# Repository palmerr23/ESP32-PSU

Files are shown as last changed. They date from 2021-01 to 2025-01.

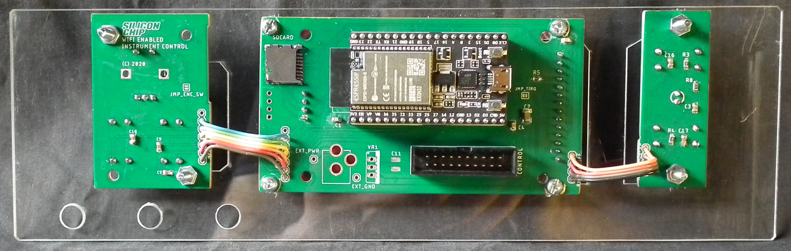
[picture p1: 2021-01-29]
Laser_templates/Control panel template 2.png

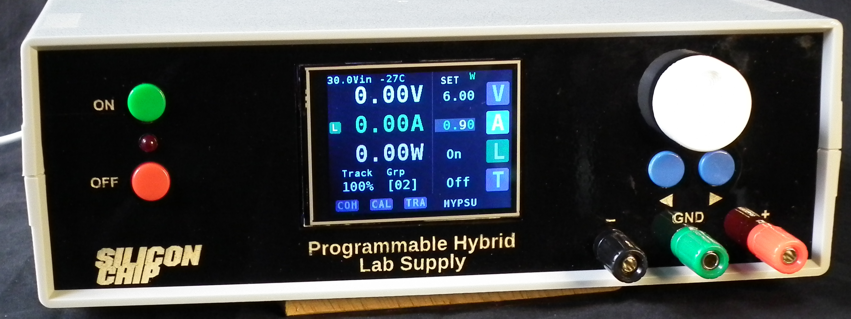
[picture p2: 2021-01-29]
Laser_templates/front panel.png

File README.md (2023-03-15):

# ESP32-PSU

These files relate to a project published in Silicon Chip magazine in May/June 2021. https://www.siliconchip.com.au/

A general purpose ESP32 breakout board, optimised for lab instrument control, and a single channel hybrid power supply module.

Two separate versions of the Open Weather code are provided for the 2.8" and 3.5" display options. They should be compiled and loaded using your own OWM token. https://openweathermap.org/appid

For the Hybrid Power Supply, only compiled code is provided for 2.8" and 3.5" versions (ILI9341 and ILI9488 LCD controllers) because the number of libraries and complexity of code would make it difficult for others to get a clean compile.   

The Laser_Templates folder has SVG files for the front and rear panels of the power supply. There are separate versions for the 2.8" and 3.5" display options. In each front panel file there are two templates: the front panel itself (with colour coded cut [outlines] and etch [labels] elements) and a second template for a panel to support the display and controller PCBs (avoiding front panel screws). A reinforcing plate for the binding posts is also included. It is fitted behnd the front panel.

The front and supporting panels were cut from 2mm acrylic and the back panel from the plastic insert provided with the case.

The laser templates are designed for a Pro'skit 203-115B instrument case (Jaycar HB5910, Altronics H0482). The templates have been tested with LightBurn, but should work with other laser cutter software. 

My front panel was made with clear acrylic, coated on the BACK with black spray paint. Wood filler, in a contrasting colour, was squeegeed into the etched labels and then polished off with very fine DRY sandpaper (240 grit). A final coat of clear spray was then appled to seal the wood filler and restore a gloss finish to the acrylic.

The project can be compiled from source, with the usual caveats that external libraries may bnot be backward compatible.

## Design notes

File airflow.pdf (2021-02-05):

## Hybrid PSU – Fan Shroud & Airflow Improvement

Feb 2021

To improve heatsink cooling, make a shroud to go between the back panel and the edge of the heatsink.
The template is in shroud.svg
I used a thin plastic cutting mat sourced from Aldi.
The edge of the plastic tucks in beside the LM2679.

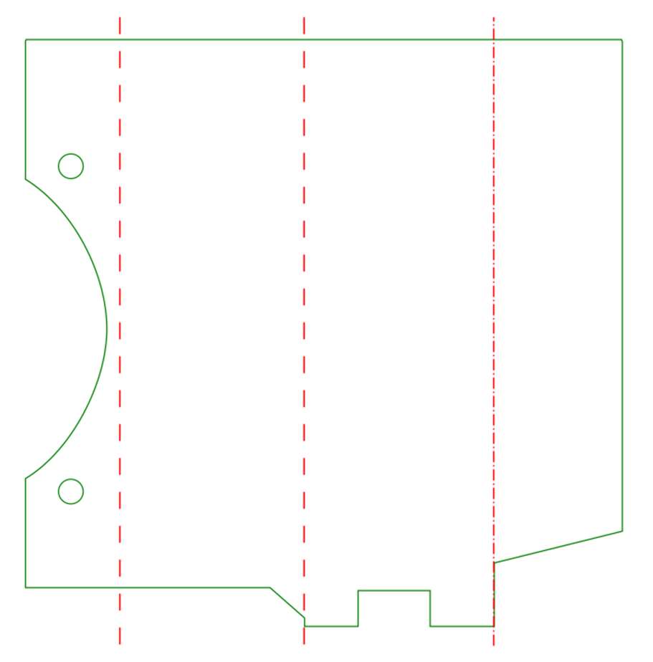
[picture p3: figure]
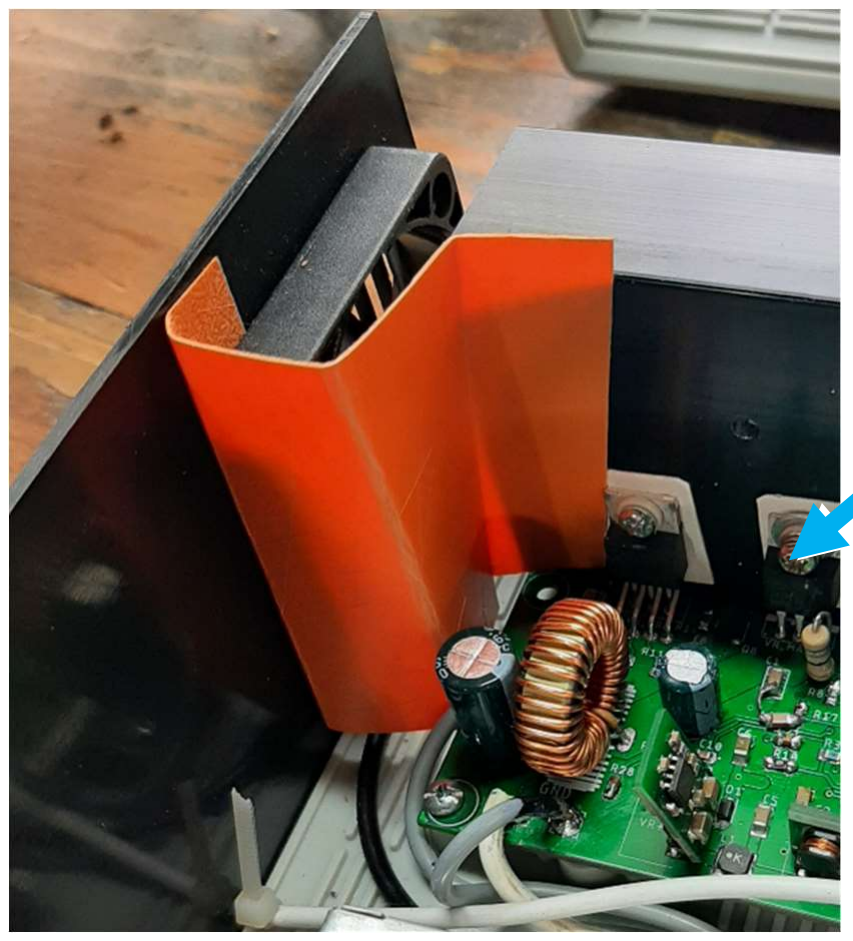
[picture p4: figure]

Also obstruct the vents in the top and bottom of the case, immediately adjacent to the fan. While more elegant solutions are possible, I simply covered the vents with packaging tape.

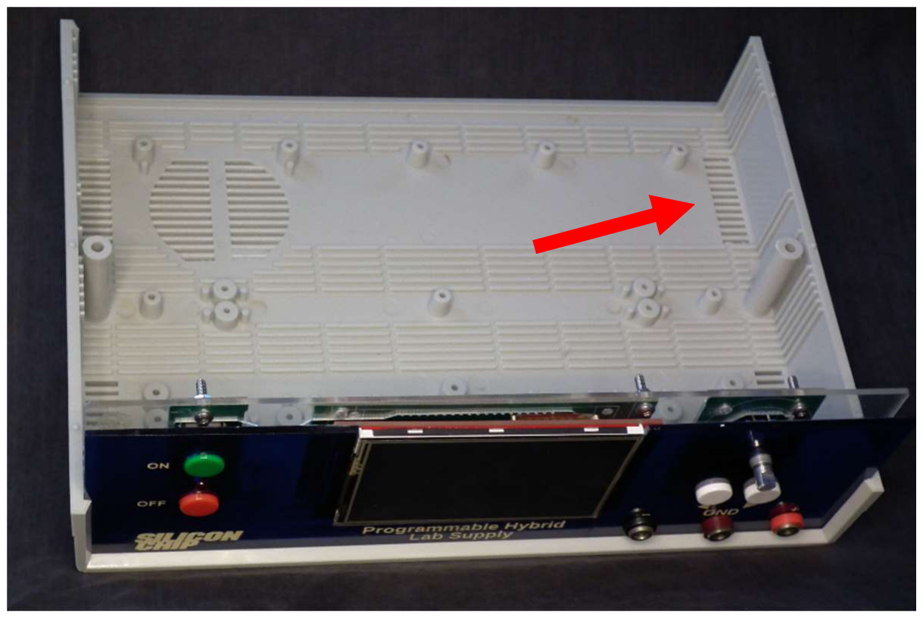
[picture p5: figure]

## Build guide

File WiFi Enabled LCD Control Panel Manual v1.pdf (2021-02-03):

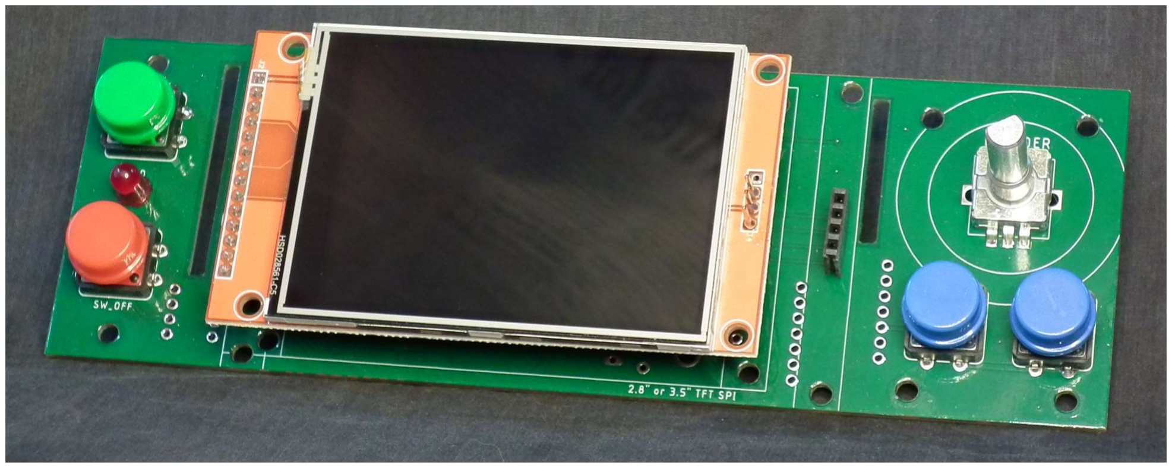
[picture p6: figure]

V1.0 – 3 Feb 2021 | ESP32 LCD Controller Manual | 1

# ESP32 LCD Controller Manual

This manual describes the features of the LCD Controller module as a stand-alone entity. All information about lab instruments that use this controller is contained in their individual manuals.
This manual is intended as a reference, construction and commissioning details are available in the relevant Silicon Chip article.

## Contents

V1.0 – 3 Feb 2021 | ESP32 LCD Controller Manual | 2

## Features

Processor: | ESP32. 32-bit, 240MHz, dual core.
Memory: | 4MB Flash, 520k RAM, full-size and micro SD CARD sockets
Display: | 2.8” or 3.5” colour LCD touch screen. Jumper-selectable touch screen interrupt.
User interface: | LCD touch panel Rotary encoder and up/down buttons Separate start/stop buttons with LED indicator

Flexible configuration: Switches and encoder are detachable, allowing flexibility of controls and panel layout.
| Several functions
IO and Expansion: | 20 pin connector carrying power, Serial RXD/TXD, I2C with an optional second channel SPI – shared with the LCD display and SD-CARD 2 x 8-bit DAC (200kHz) 2 x 12-bit ADC (27kHz under non-DMA operation) 3 uncommitted GPIO pins. 17 total GPIO pins. All specialist pins other than SPI, can be repurposed as GPIO and PWM. Additional GPIO pins are available if onboard switches and encoder are not required, via the REM_ON_OFF and REM_SCRUB headers.
Communication: | WiFi (802.11 b/g/n 2.4GHz). 150 Mbps maximum throughput. QoS (802.11 e) for multimedia applications. Station or soft-AP modes, TCP, UDP, mDNS over IPV4 and IPV6. Webserver and web client functions. Bluetooth and BLE TTL and USB serial. Extensive examples provided for all communication modes.
Powering: | USB 5-12V via barrel jack and regulator 5V via expansion header 3.3V up to 50mA available, via the ESP32’s onboard regulator.
Updating | Arduino (and other IDE) native programming Off-the-air (OTA) binary uploads.

SCPI over WiFi (802.11 b/g/n/e/i) for PC control or master control of multiple modules.

## Overview

The controller module consists of a central section with the display on the front and the ESP32 DevKitC module plugged into headers on the rear. Standard 2.8” or 3.5” SPI touchscreen LCD modules are supported.
To one side of the LCD is a detachable panel containing a LED and two tactile switches, intended as on/off buttons. On the other side two momentary switches and a rotary encoder are mounted on a second detachable panel, intended to complement the on-screen touch menu, in setting the instrument’s configuration and control values.
The controller’s expansion capabilities are provided on a 20 pin header and include I2C, SPI, serial, GPIO, ADC, DAC and power (3.3V and 5V) pins. It can be powered via a USB cable, an external 7-12V plugpack, or from the ‘controlled’ board.

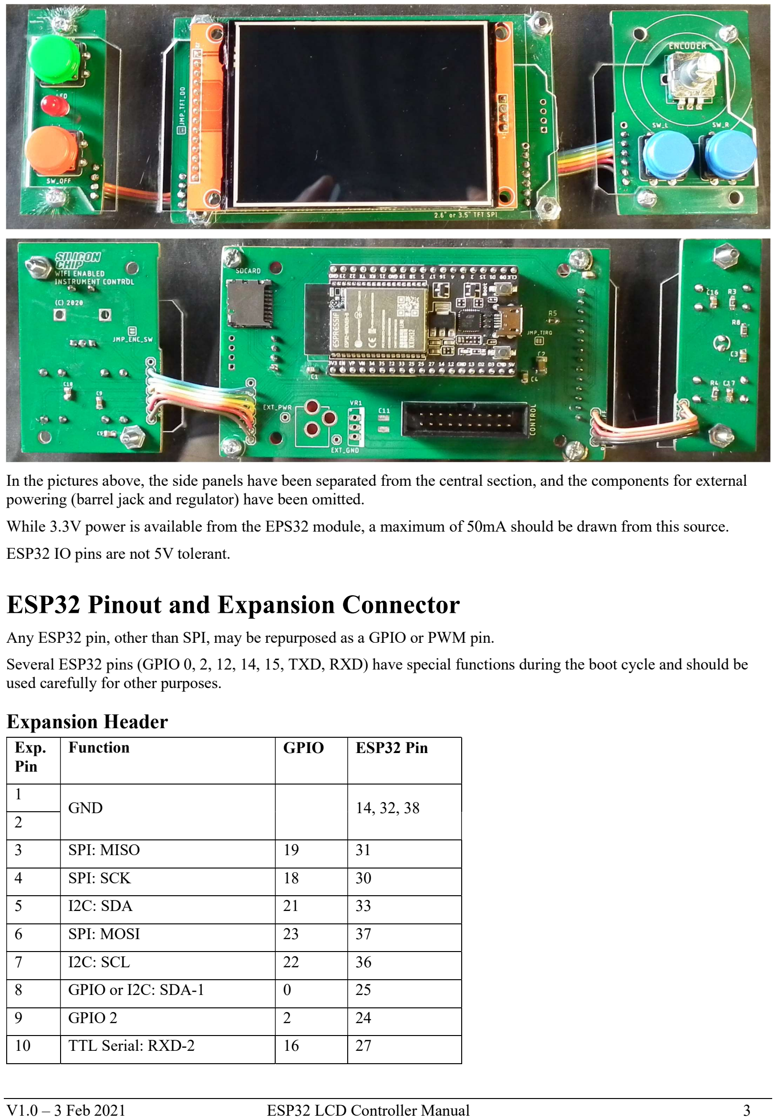
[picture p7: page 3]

V1.0 – 3 Feb 2021 | ESP32 LCD Controller Manual | 3

In the pictures above, the side panels have been separated from the central section, and the components for external powering (barrel jack and regulator) have been omitted.
While 3.3V power is available from the EPS32 module, a maximum of 50mA should be drawn from this source. ESP32 IO pins are not 5V tolerant.

## ESP32 Pinout and Expansion Connector

Any ESP32 pin, other than SPI, may be repurposed as a GPIO or PWM pin.
Several ESP32 pins (GPIO 0, 2, 12, 14, 15, TXD, RXD) have special functions during the boot cycle and should be used carefully for other purposes.

### Expansion Header

Exp. Pin | Function | GPIO | ESP32 Pin
1 | GND | | 14, 32, 38
2
3 | SPI: MISO | 19 | 31
4 | SPI: SCK | 18 | 30
5 | I2C: SDA | 21 | 33
6 | SPI: MOSI | 23 | 37
7 | I2C: SCL | 22 | 36
8 | GPIO or I2C: SDA-1 | 0 | 25
9 | GPIO 2 | 2 | 24
10 | TTL Serial: RXD-2 | 16 | 27

V1.0 – 3 Feb 2021 | ESP32 LCD Controller Manual | 4
Exp. Pin | Function | GPIO | ESP32 Pin
11 | TTL Serial: TXD-2 | 17 | 28
12 | SW_ON | 4 | 26
13 | DAC1 or GPIO | 25 | 9
14 | DAC2, GPIO or SCL-1 | 26 | 10
15 | ADC1-7 or GPIO (input) | 35 | 6
16 | SW_OFF | 12 | 13
17 | ADC1-6 or GPIO (input) | 34 | 5
18 | +5V | | 19
19 | +3.3V | | 1
20 | +5V | | 19

### REM_ON_OFF Header

Exp. Pin | Function | GPIO pin

1 GND
2 +3.3V
3 | SW_OFF | 12
4 | SW_ON | 4

### REM_ENC Header

Exp. Pin | Function | GPIO pin

1 GND
2 +3.3V
3 | CRTL_L | 14
4 | CTRL_R | 27
5 | ENC_A | 33
6 | ENC_B | 32
7 | Encoder switch (jumper LK3) | 26

V1.0 – 3 Feb 2021 | ESP32 LCD Controller Manual | 5

### ESP32 Pin Assignments

ESP32 Pin | Function | GPIO pin | ESP32 Pin | Function | GPIO pin
1 | 3V3 power (output) | | 20 | DO NOT USE
3 22 | DO NOT USE EN, SVP, SVN | | 21 | SD0, SD1, CLK 2
4 | | | 23 | Touch CS | 15
5 | ADC1-6 or GPIO | 34 | 24 | SD CS | 2
6 | ADC1-7 or GPIO | 35 | 25 | GPIO, SDA-1 | 0
7 | Encoder | 32 | 26 | On switch | 4
8 | Encoder | 33 | 27 | GPIO, RXD2 | 16
9 | DAC1 or GPIO | 25 | 28 | GPIO, TXD2 | 17
10 | DAC2, GPIO or SCL-1 | 26 | 29 | TFT CS | 5
11 | Switch R (rotary encoder side) | 27 | 30 | SCK | 18
12 | Switch L (rotary encoder side) | 14 | 31 | MISO | 19
13 | Off switch | 12 | 32 | GND
14 | GND | | 33 | SDA | 21
15 | D_C (TFT) | 13 | 34 | RXD | RXD
16 DO NOT USE | SD2, SD3, CMD | | 35 | TXD | TXD
17 | | | 36 | SCL | 22
18 | | | 37 | MOSI | 23
19 | 5v power (input) | | 38 | GND

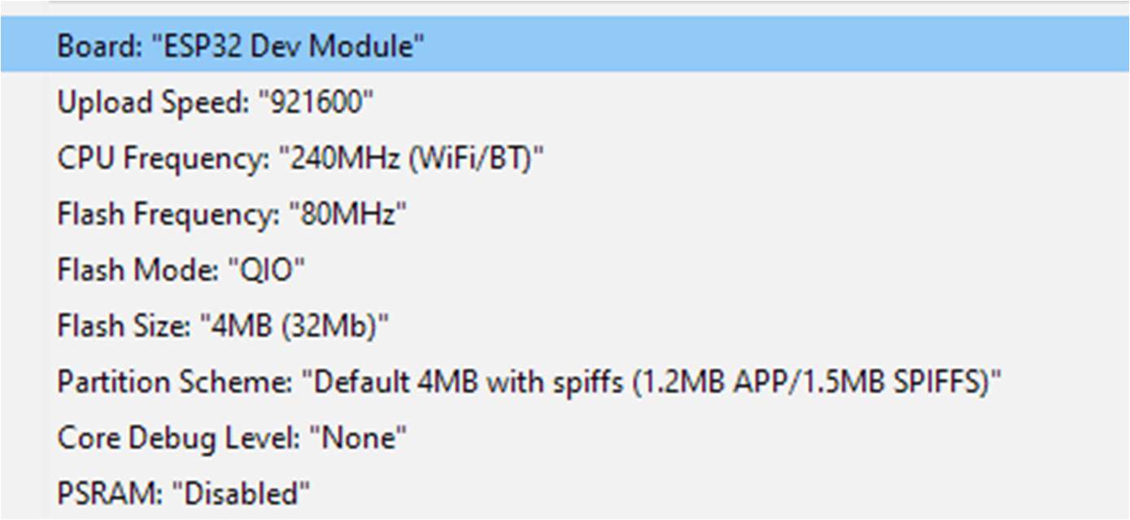
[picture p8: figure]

V1.0 – 3 Feb 2021 | ESP32 LCD Controller Manual | 6

## Software and Libraries

The controller can be programmed using the Arduino IDE by loading the ESP32 files into Board Manager.
- Add the entry https://dl.espressif.com/dl/package_esp32_index.json to the Additional Boards Manager URLs list in the File > Preferences menu.
- Open the Boards Manager (Tools > Board > Board Manager) search for ESP32 and click ‘Install.’
- The board settings used for the Expressif DevKitC (WROOM 32) boards are:

The controller has been tested with the following general Arduino libraries:
- Adafruit GFX graphics.
- Adafruit ILI9488 and ILI9341.
- XPT2046_Touchscreen (Paul Stoffregen) in polled mode.
- ESProtary and Button2 (Lennart Hennigs) – ESP8266 libraries work on ESP32.
- ESP32 WiFi and EEPROM libraries.
- Adafruit ADS1015.

The ESP32 DevKitC example programs File > Examples > Examples for ESP32 Dev Module should function correctly.
The board may be programmed via USB serial or over WiFi, as explained in the ESP32 Update > OTA example. Other programming environments, compatible with the ESP32, may also be used.

## Communications

Multiple comms channels are supported, and can be used as described in the example programs for the ESP32.
- USB serial – which should be isolated if an alternate ground path is possible.
- WiFi - TCP/IP, UDP and Telnet are all supported.
Note: WPS connection does not function reliably with the ESP32 modules (as at January 2021).
- Serial (logic-level) up to 1MHz or more.

ESP32 pins have only modest protection against static electricity and wrong voltages (they are not 5V tolerant). Therefore, they should not be connected directly to remote equipment. Use opto-isolators or a RS232 or RS485 converter for serial communications.

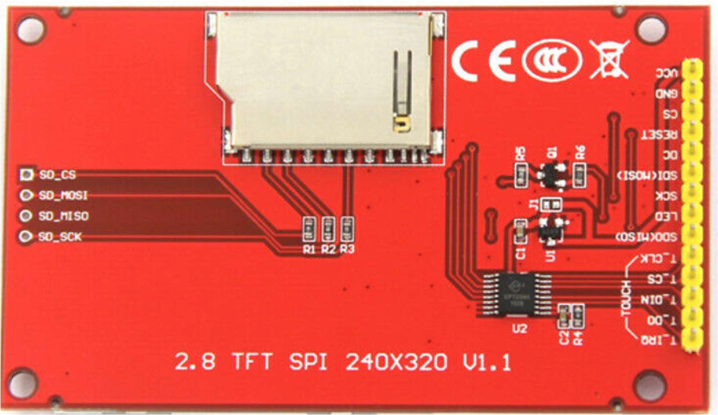
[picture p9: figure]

V1.0 – 3 Feb 2021 | ESP32 LCD Controller Manual | 7

## Display

The controller can support any SPI LCD module with the same pinouts as the popular ILI9341 (2.8” 240 x 320) or ILI9488 (3.5” 320 x 480) Arduino modules. The SD card pins on the controller are aligned specifically for these two displays.

MOSI and SCK are shared between the LCD screen, touch panel and the onboard SD card.
Do not connect MISO if using an ILI9488 controller as it does not release the MISO line when CS is inactive. MISO is available to the TFT via a jumper LK4 for other controllers.
The interrupt pin for the touch panel controller is shared with SD_CS and is enabled by bridging LK1.
Signal | Pin (ESP 32 DevKitC) | ESP Logical | Use
MOSI | 37 | IO 23 | TFT, Touch, SD
MISO | 31 | IO 19 | Touch, SD (Jumper for TFT)
SCK | 30 | IO 18 | TFT, Touch, SD
RST | N/C – pullup | – | TFT
DC | 15 | IO 13 | TFT
CS | 29 | IO 5 | TFT
T_CS | 23 | IO 15 | Touch
SD_CS | 24 | IO 2 | SD
T_IRQ | 24 | IO 2 | Touch
LED & VCC | 5V | – | All

V1.0 – 3 Feb 2021 | ESP32 LCD Controller Manual | 8

## Troubleshooting

Symptom | Likely cause | Remediation
Touch panel not responding. | Touch panel is rotated 180 from LCD. | Rotate the touch panel 180 by changing the touchscreen’s screenRotation() parameter (1 or 3 is usually correct for horizontal screen orientation)
Touch not centred on required screen coordinates. | Touch panel out of register with LCD. | Calibrate the touch panel (library dependent).
Rotary encoder skipping values or moving multiple steps per click. | Processing too slow to capture all pulses. | Faster processing cycle – particularly using non-blocking code, interrupt-driven encoder processing.
| Encoder missing steps or not scaling steps : clicks correctly. | Faster processing cycle (see above). Change the encoder steps_per_click setting. Buy a new encoder!

## PCB Layouts

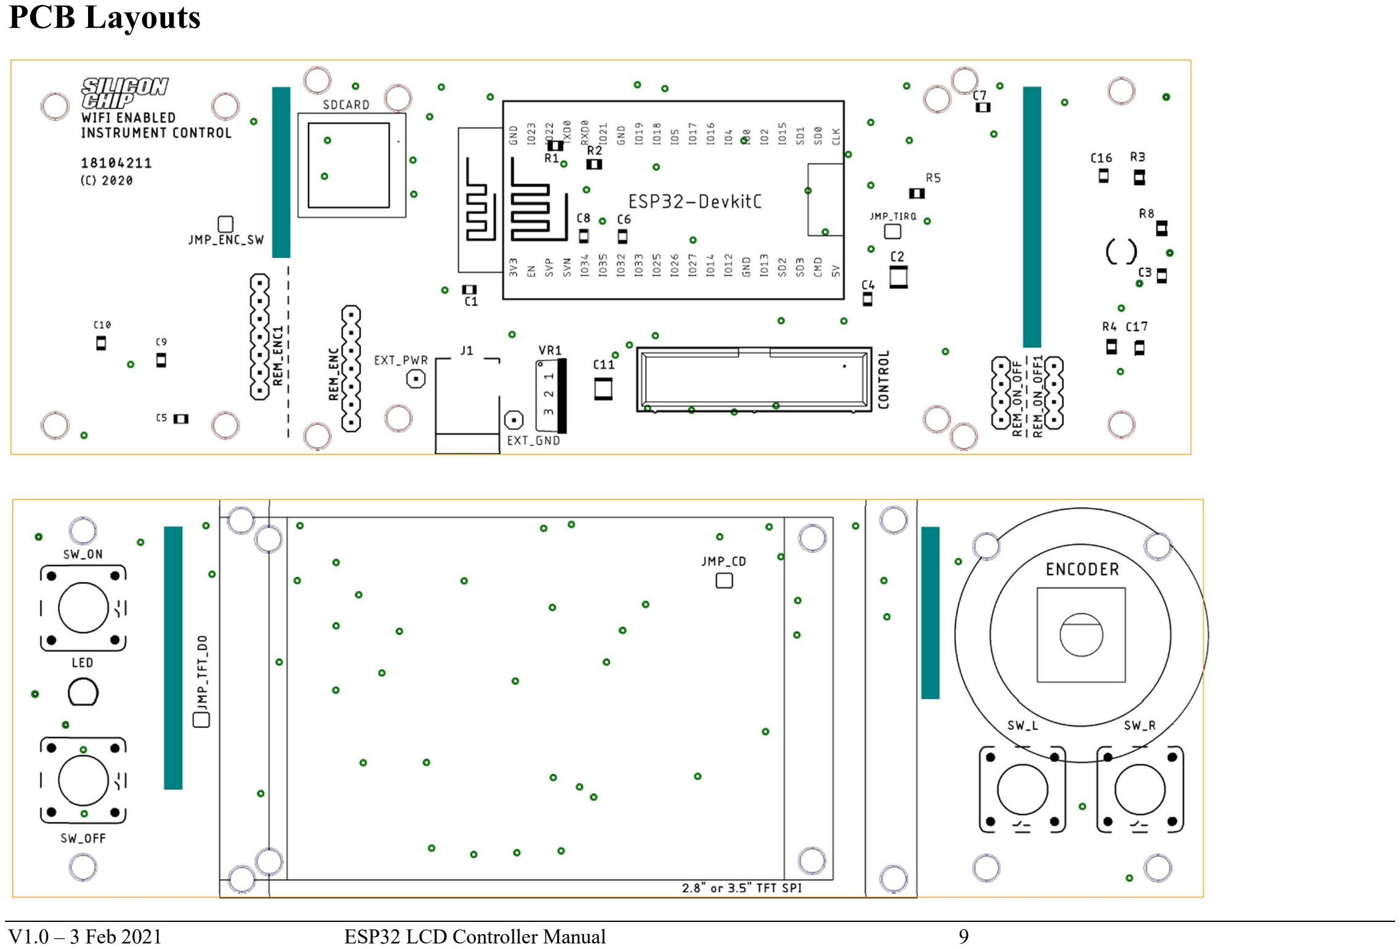
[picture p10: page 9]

V1.0 – 3 Feb 2021 | ESP32 LCD Controller Manual | 9

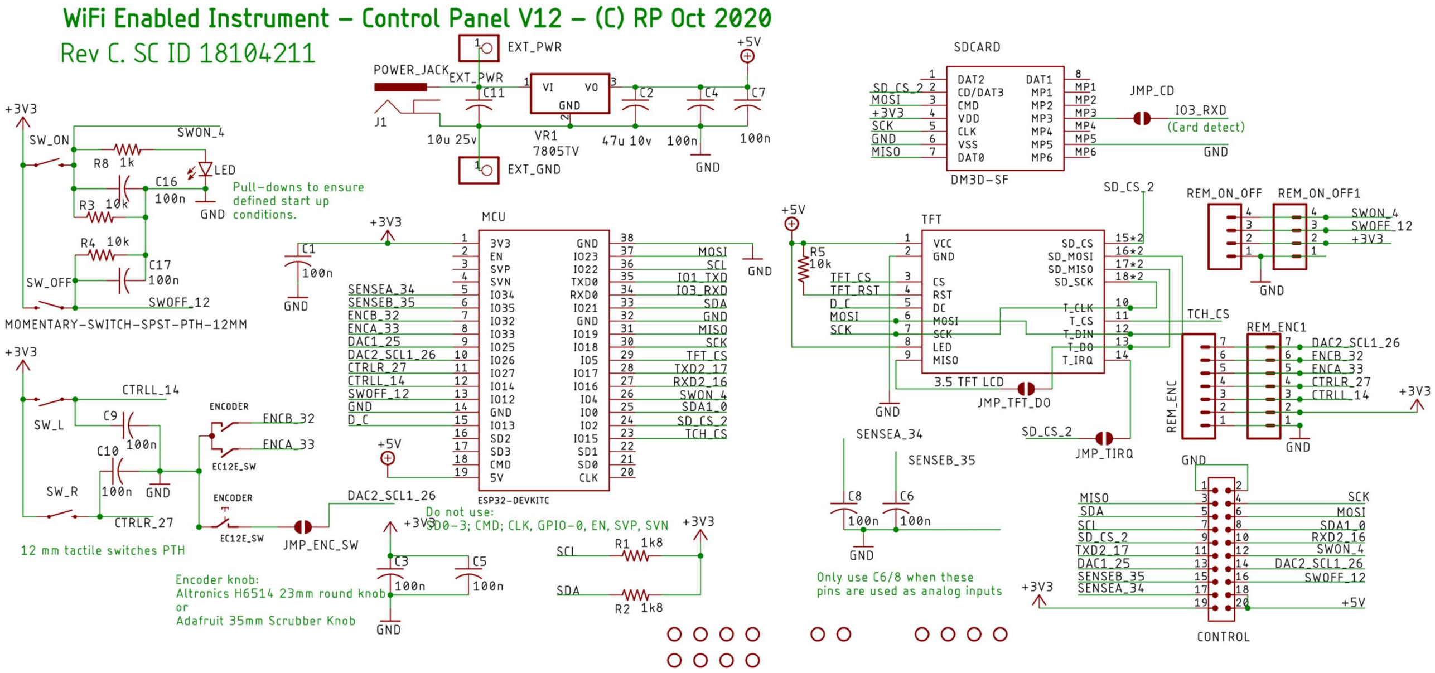
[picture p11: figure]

V1.0 – 3 Feb 2021 | ESP32 LCD Controller Manual | 10

## Schematic

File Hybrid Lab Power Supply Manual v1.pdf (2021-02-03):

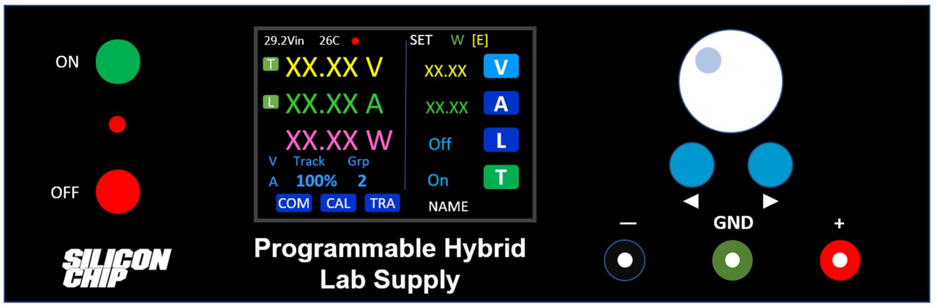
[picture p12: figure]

V1.0 – 3 Feb 2021 | Programmable Hybrid Supply Manual | 1

# Programmable Hybrid Lab Supply Manual

This manual describes the features of Programmable Hybrid Lab Supply. It should be read in conjunction with the LCD Controller manual, where some generic features and specifications of the control interface are documented.

## Key Features

- Hybrid architecture with SMPS pre-regulation and linear final regulation for high efficiency and performance.
- 26V maximum voltage. 24V @ 3.5A, 16V @ 5A.
- Setting resolution 10mV and 10mA.
- Control resolution better than 1mV and 1mA
- Excellent line and load regulation.
- Soft Start parallels real world PSU performance when output is switched on, avoiding ‘crash’ starts.
- Remote monitoring and control via WiFi.
- Multiple units can coordinate to deliver flexible stacking and tracking options.
- HTTP, Telnet and isolated USB serial control supported using universal SCPI commands.
- Compact, lightweight and low heat dissipation.
- Universal AC input (100-240 VAC, 50-60 Hz).

V1.0 – 3 Feb 2021 | Programmable Hybrid Supply Manual | 2

## Contents

© 2021 Richard Palmer

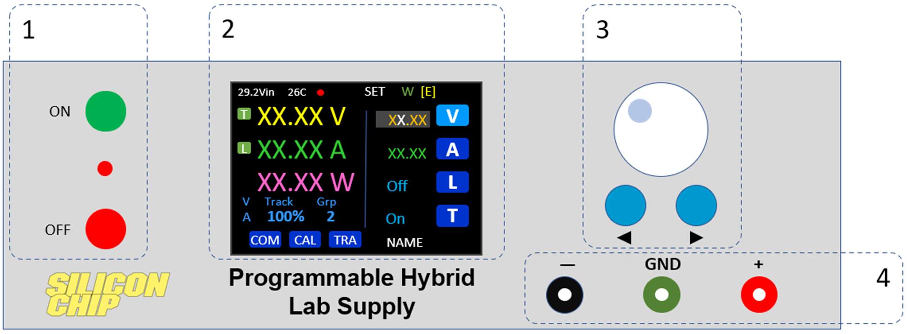
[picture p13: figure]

V1.0 – 3 Feb 2021 | Programmable Hybrid Supply Manual | 3

## Safety

Isolated remote control and monitoring via WiFi is the recommended approach for this instrument.
1. Once commissioned, do not make a non-isolated USB connection to the instrument.
- Almost certain damage will occur if the + terminal is connected to GND and a non-isolated USB connection is also made. This connection would create a ground loop of the full output voltage of the supply, as the ESP32’s USB ground is hard wired to the – terminal of the supply.
- Differing ground potentials may also cause damage if the – terminal is connected to GND terminal unless a USB isolator is employed where a mains earth differential is present between the computer and the supply.
- Both the computer and instrument may be damaged in either case.

Units connected in parallel must always have the same output voltage set.
2. Multiple supplies connected in parallel must ALWAYS have voltage tracking enabled (VOL = On), and be in the same enabled (T = On) tracking group (Grp = same).
Damage to one or more supplies may otherwise occur.

## Front Panel

### 1 On/Off buttons and LED indicator 2 Control touch screen 3 Numeric setting controls 4 Output binding posts

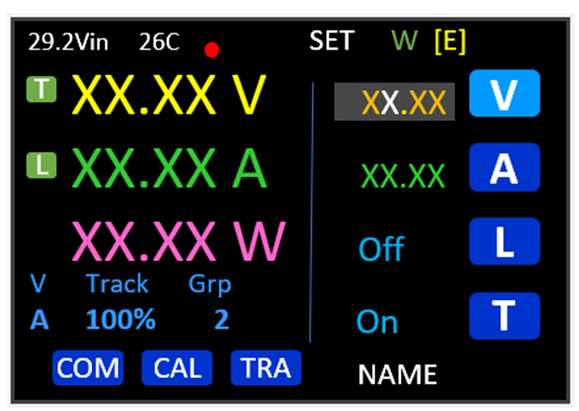
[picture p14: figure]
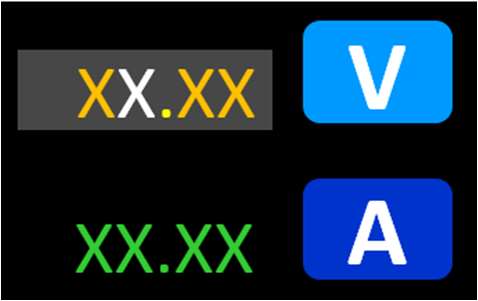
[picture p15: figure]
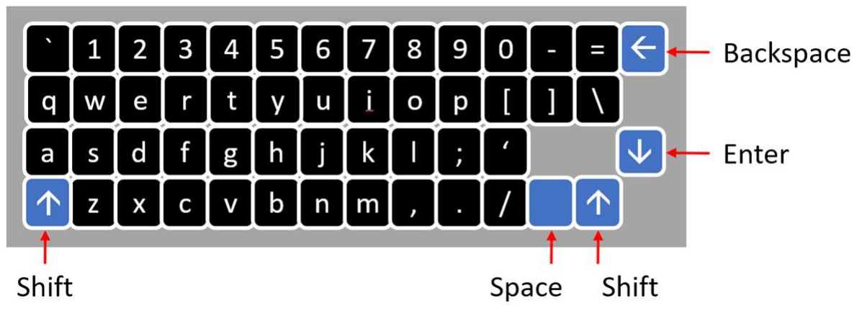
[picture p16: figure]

V1.0 – 3 Feb 2021 | Programmable Hybrid Supply Manual | 4

## General Operation

## On/Off Buttons

The buttons to the left of the LCD screen turn the output On and Off.
The LED indicates the current state of the output, which may also be controlled remotely.

## Screens and Menus

Menu items are selected using the dark blue buttons on the touch screen.
For instance, on the main screen there are four buttons V, A, L & T on the right-hand side, which set specific operational values. The buttons change colour when selected or to indicate their status (see Main screen settings, below).
Three smaller sub-menu buttons COM (communication), CAL (calibration) & TRA (tracking) are arranged across the bottom left of the screen.

### Changing numeric values

Select the item with its associated on-screen button, and use the numeric setting controls (rotary encoder and buttons) to alter settings. When a setting is selected its background is highlighted as is one of the digits. The rotary encoder will change the value by 1 unit of the highlighted digit per click. Clockwise rotation increases the value, anti-clockwise decreases it.

Voltage (V) setting selected and the 'tens' digit being edited.

The highlighted digit is changed with the buttons under the encoder (digit buttons). The left button will move the highlight to a more significant digit, and the right button to a less significant digit.

### On/off settings

Touching a selection button for on/off controls will change the value, as will rotating the encoder knob or pressing the numeric setting buttons (right button or clockwise rotation = On, left button or anti-clockwise rotation = Off).

### Changing text values

An on-screen keyboard is displayed for test values when the associated selection button is touched. As the individual characters are small, a stylus is recommended to operate the on-screen keyboard. When a character is touched, it is appended to the
end of the string. Backspace deletes the last
character typed.
Shift buttons at the lower right and left change the case off alphabetic characters and which symbols or numbers are displayed.
The Enter button saves the value and returns to the menu screen.
Processing of the underpinning menu screen is suspended while the on-screen keyboard is active.

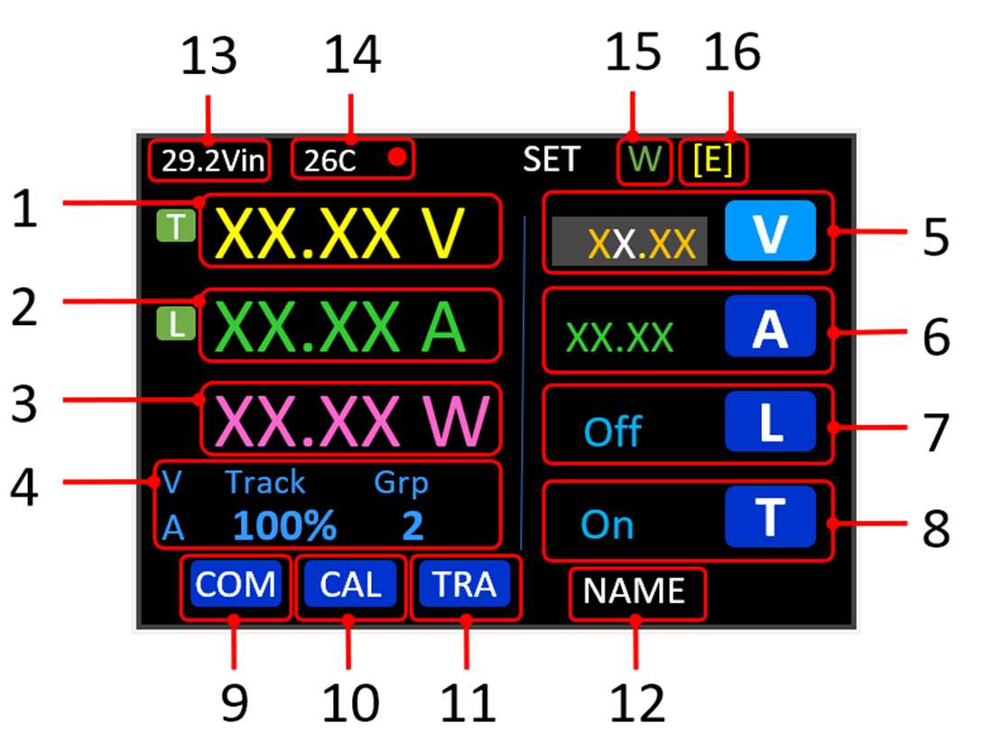
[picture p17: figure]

V1.0 – 3 Feb 2021 | Programmable Hybrid Supply Manual | 5

## Main Screen

### 1. Output voltage reading 2. Output current reading 3. Output power reading 4. Tracking voltage reduction value and group ID

(only visible when Tracking is enabled)

5. Output voltage setting button and value 6. Output current setting button and value 7. Current limit enable button 8. Tracking enable button 9. Communication menu button 10. Calibration menu button 11. Tracking menu button 12. Instrument name 13. Input voltage reading 14. Heatsink temperature 15. WiFi connection indicator (visible on all screens) 16. Save values to EEPROM pending indicator (visible on all screens)

### Main screen settings

Settings are saved automatically to EEPROM 60 seconds after the last value was changed. The [E] indicator is displayed when a save is pending.
Values are not saved more regularly as EEPROM has a limited save cycle lifetime (> 10,000).

Voltage
Touch the V button on the screen to enable voltage control setting.
Use the rotary encoder and buttons, as described in General Operation above, to set the desired output voltage. Output voltage will be displayed as 0.00 until the output is turned on. The actual output voltage may be reduced if current limiting is active (L button), or group tracking is enabled (T button).

Current
Set the desired output current limit with the A button on the screen.

Current Limiting
Current limiting may be turned On or Off by touching the L button. The rotary encoder and buttons will also change this setting, as described in General Operation above.

Tracking
Tracking functions may be enabled or disabled by touching the T button. Once selected, the rotary controls and digit buttons alter the value, as for current limiting. Specific tracking functions are enabled on the TRA(tracking) sub-menu (below).

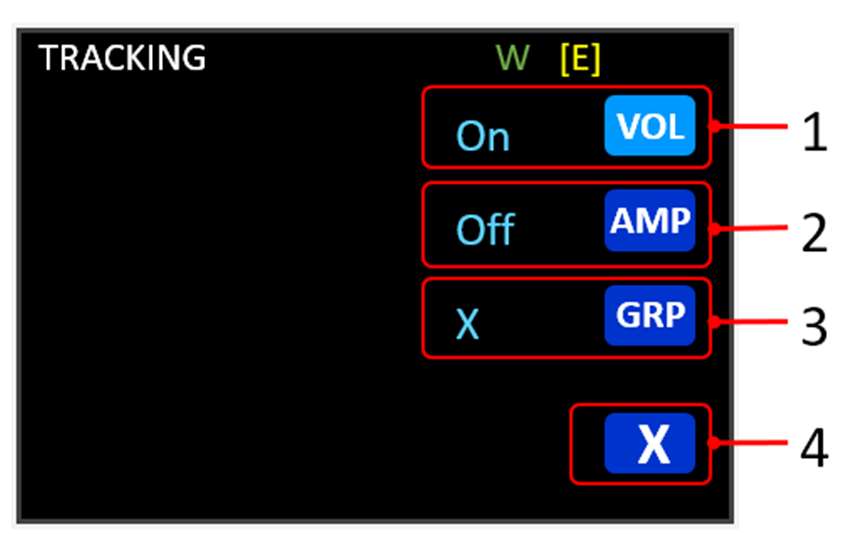
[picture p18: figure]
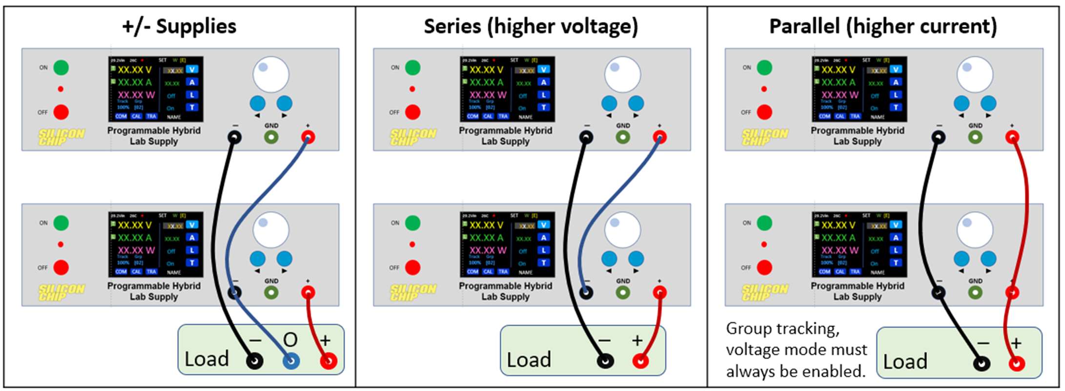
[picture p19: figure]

V1.0 – 3 Feb 2021 | Programmable Hybrid Supply Manual | 6

## Tracking Screen

### 1. Voltage tracking mode indicator and button 2. Voltage tracking mode indicator and button 3. Tracking Group 4. Menu exit button

The tracking screen is entered by touching the TRA button on the
main screen, and exited with the X button.
Basic (VOL and AMP both Off). When Tracking is enabled on the main menu, all units will reduce their output voltage if any of the group current limits. The entire group will reduce its output voltage by the same proportion as the member of the group which is limiting by the greatest amount.
Voltage (VOL). The voltage set on any of the group’s controllers affects all units in the group. ‘V’ is displayed on the main screen next to the ‘T’ button when this mode is set set and tracking is active.
This mode must always be enabled when supplies are connected in parallel.
Current (AMP). The current set on simplest mode, where the current limiting function on any instrument reduces the Voltage of all members of the tracking group by the same proportion. ‘A’ is displayed on the main screen next to the ‘T’ button when this mode is set and tracking is active.
Current and Voltage tracking modes can be independently enabled.
Both modes are commonly engaged when providing +/- power supplies, where the commoned terminals are connected to the 0V rail of the circuit being powered.
In any of the tracking modes:
- The On and Off buttons on any controller will control all units in the tracking group, even if none of the current or voltage tracking modes, above, are enabled.
- Short circuit or overvoltage protection triggering on any active member of a tracking group will cause all other active units to disconnect their outputs.

## Combining Multiple Supplies

Floating outputs on the power supply allows flexible configuration of multiple units. Units may be connected in series (higher output voltage) and parallel (higher current), as well as the common +/- supply arrangement.

While it is possible to operate most modes, other than parallel, with independent controls, tracking can be enabled to allow simultaneous voltage reduction on current limiting, or common control of all supplies in a group from any of the group’s control screens.
Multiple instrument groups may be configured. Only instruments in the same tracking group will respond to
commands from another unit.

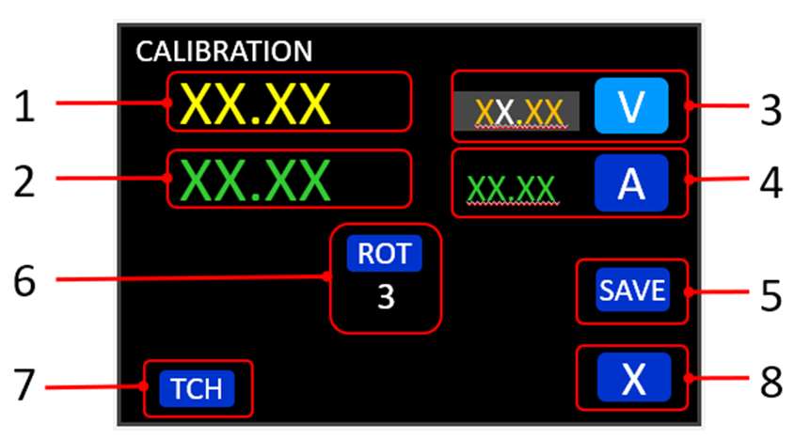
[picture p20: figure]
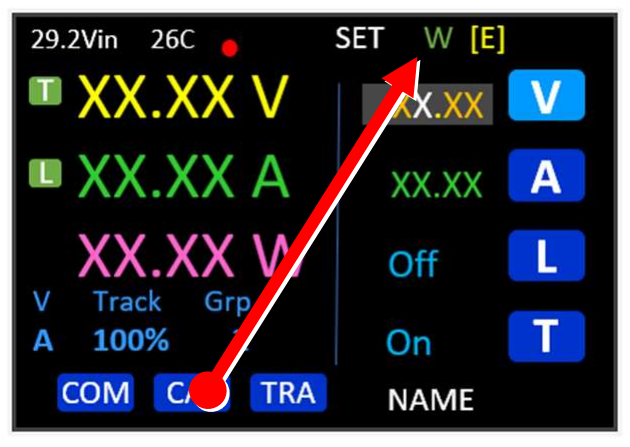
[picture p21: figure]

V1.0 – 3 Feb 2021 | Programmable Hybrid Supply Manual | 7

All units in the group will enter the same mode, whenever it is changed on any member of the group, as mode changes are broadcast to the group as they are set.
If group tracking is enabled, current limiting on one unit will be mirrored (if L & T are both On) on the other units, reducing the output voltage by the same proportion as the limiting supply. This provides predictable behaviour where the voltages are not equal (e.g. +12V, -5V).

### +/- Supplies

Several units may be connected together to provide +/- supplies. Depending on the group tracking mode selected, voltage and current limits may be controlled together, or separately (see below).

### Series

To increase the available output voltage, units may be connected in series.
If voltage tracking is enabled and the maximum voltage outputs of both units are not the same, two conditions may occur.
- If the unit with the higher maximum voltage is used to control both units, the lower voltage unit will not exceed its maximum voltage setting. The actual setting will be displayed on the lower voltage unit.
- If the unit with the lower maximum voltage is used to control both units, the higher voltage unit will not be able to be set beyond the limit of the lower voltage unit.
Current limiting in one unit will cause the other unit to reduce its output voltage proportionately, even if its set current limit has not been reached.

### Parallel

Several units may be connected in parallel to increase the available current. Use this mode with great care.
For this mode, voltage tracking MUST be enabled, as different output voltage settings will cause unpredictable results. Warning: Multiple supplies connected in parallel must ALWAYS have voltage tracking enabled (VOL = On), and be in the same enabled (T = On) tracking group (Grp = same).
Damage to one or more units may otherwise occur.

## Calibration Screen

### 1 Voltage reading 2 Current reading 3 Voltage offset (calibration) button and value 4 Current offset (calibration) button and value 5 Voltage and current offset update (save) button 6 Touch screen rotate button and value 7 Touch panel calibration menu button 8 Menu exit button

The Calibration screen is entered by touching the CAL button on the main screen, and exited with the X button.

### Screen Rotation

Some TFT displays have the touch panel rotated by 180 degrees. If your touch
panel does not appear to be responding, tap the main screen diagonally opposite to the CAL button. If the Calibration menu appears, tap the ROT button in the middle of the screen to rotate the touch settings.
The number under the ROT button will be 1 or 3 depending on the current touch panel rotation.

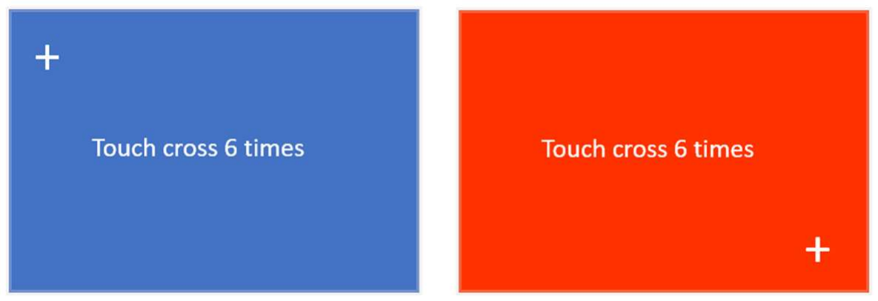
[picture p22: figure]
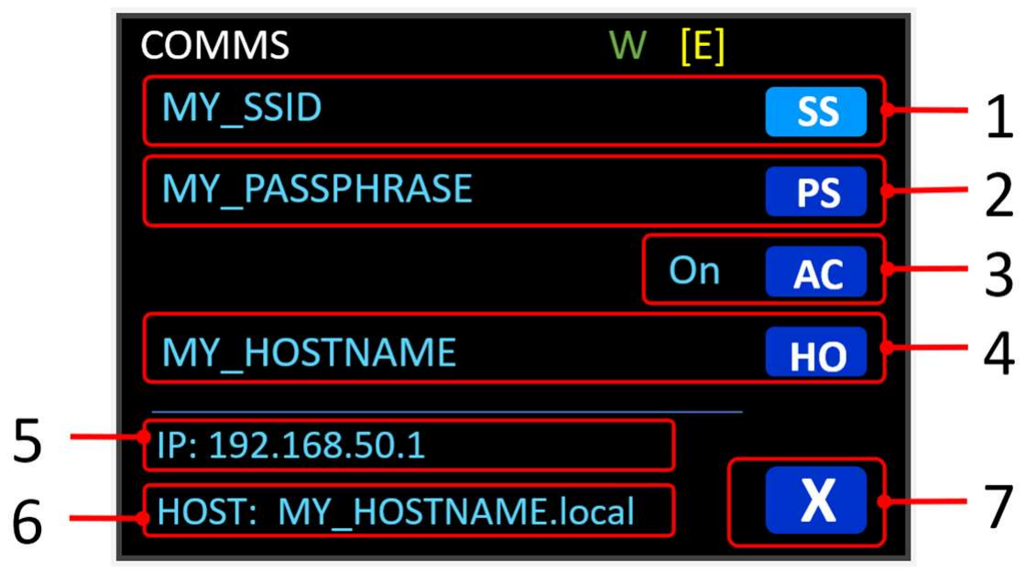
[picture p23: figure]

V1.0 – 3 Feb 2021 | Programmable Hybrid Supply Manual | 8

### Voltage calibration

- Set the output voltage to a value close to 25V.
- Disconnect any load and attach a voltmeter to the binding posts. Do no connect anything to the Earth (green) post.
- Turn on the output and select voltage calibration.
- Using the numeric value controls, enter the difference between the voltmeter reading and the value displayed on the left of screen. If the external voltmeter is higher, the value entered will be positive.
- Touch the SAVE button to save the result. This will also exit the Calibration menu.
- Wait for the [E] indicator to extinguish before turning the instrument off, so that the new calibration value is permanently stored in EEPROM.

### Current calibration

- Connect a load (a 1 ohm 10W resistor is ideal) and ammeter in series between the + and – terminals. Do no connect anything to the Earth (green) post.
- On the main screen, set the output voltage so that the current will be more than 1 Amp (more than 3 Amps is preferred).
- The output may be turned off and on during the following operation, if desired.
- Enter the Calibration screen and select current calibration.
- Using the numeric value controls, enter the difference between the ammeter reading and the value displayed on the screen. If the external ammeter is higher, the value entered will be positive.
- Touch the SAVE button to save the result. This will also exit the Calibration menu.
- Wait for the [E] indicator to extinguish before turning the instrument off, so that the new calibration value is permanently stored in EEPROM.

### Touch calibration

Touch calibration is only required if the control buttons or on-screen keyboard touch positions are offset from the display.
Touching the screen six times on the + sign at the top left corner of the blue screen, and then 5 times on the + sign at the bottom right corner of the red screen calibrates the touch screen relative to the display panel.
A stylus is recommended for this operation.

## Communications Screen

### 1 SSID button and value 2 WiFi Passphrase button and value 3 Autoconnect button 4 Hostname (instrument name)

button and value

### 5 IP address reading 6 DNS hostname reading 7 Menu exit button

The Communications screen is entered by touching the COM button on the main screen, and exited with the X button.

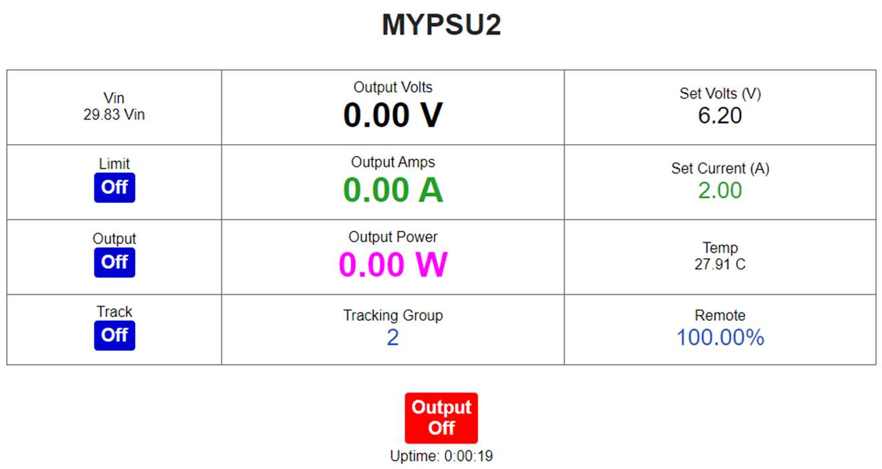
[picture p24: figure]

V1.0 – 3 Feb 2021 | Programmable Hybrid Supply Manual | 9

### Changing settings

Select the appropriate blue button to change the SSID or WiFi passphrase using the on-screen keyboard, as outlined above. Hostname changes will not affect the Web address (HOST:) until the WiFi connection is refreshed (AC Off then On).
To satisfy the requirements of IEEE 802.11 value and are case-sensitive.
- SSIDs may be up to 32 characters in length. While any valid 8-bit value (e.g. special characters) is permitted, non-alphabetic and non-numeric values should be used with care.
- Passphrases must be between 8 and 32 characters long (WPA2 enforces an eight character minimum). Any legitimate 8-bit value is acceptable.

## Remote Control

## Web Interface

A simple web interface is provided for the supply. It is accessible from the web address indicated on the COM screen, (on the standard Port 80). Using the example above, the URLs would be:
http://192.168.50.1
or
http:// MY_HOSTNAME.local

Functionality is limited to monitoring values and settings, as the interface is not password protected, and there is a ‘big red button’ that will disconnect the output.

## SCPI Communication

Standard Commands for Programmable Instruments (SCPI) was developed in the early 1990’s to provide a common syntax and command structure for programmable instruments from power supplies to oscilloscopes and beyond. It was designed as a master-slave protocol, with the controlling software always being master. While it was originally implemented on the GPIB bus (IEEE 488) other protocols, such as serial (including USB serial) and Telnet, are now commonly used.
The IVI Foundation, which is the successor to the non-profit SCPI Consortium, has a website with exhaustive documentation on SCPI and more recently developed, and more flexible instrument communication protocols such as VISA and VXI. https://www.ivifoundation.org/specifications/default.aspx
SCPI commands can be processed from several sources:
- A TELNET connection on Port 5025, for instance from EEZ Studio.
Note: When issued via Telnet or Serial USB, tracking commands are only re-broadcast to the entire group when the appropriate tracking mode is enabled (TRAC:VOLT, TRAC:CURR).
TRAC:ESTO is rebroadcast to the group when tracking (T) is enabled on the connected unit.
- A command packet from a member of the same tracking group as this instrument via UDP packet on Port 8888. (Messages for other tracking groups are read and discarded).
While USB Serial terminal, such as the Arduino Serial Monitor can also be used, significant care needs to be taken to avoid ground loops. (See the safety warning at the beginning of this document). It is highly recommenced that an isolated USB serial connection be used to avoid damage to the computer or instrument. USB Serial commands are equivalent to Telnet.

### SCPI Command Format

Commands consist of case-sensitive keywords, separated by colons, and each keyword may have parameters associated with it, e.g. “:SET:VOLTage 350 mV” or “:MEASure:VOLTage?”

V1.0 – 3 Feb 2021 | Programmable Hybrid Supply Manual | 10

Commands ending in a question mark are queries, and the instrument should return a value or set of values to any query.
Parameters may be integers, floating point numbers or strings, depending on the command. Numeric commands may be followed by a unit, such as V, mV, A or mA.
Each command, such as “MEASure” can be issued using the full form or by using an abbreviation, which is always the part in upper case, and almost always four characters long. Thus “:MEAS:VOLT?” is equivalent to “:MEASure:VOLTage?”
Some SCPI rules for this instrument:
- Commands are case sensitive. “ABCX” is not equivalent to “aBCX”
- There must be one or more spaces between a command and its argument.
- There may be one or more spaces between an argument and its unit specifier
- No other spaces are permitted within or between commands. For instance, “:INST:NAME Fred” (no extra spaces) is legal and “: INST : NAME Fred” (extra spaces) is illegal.
- All commands must start with a ‘*’ or a ‘:’, and colons must be inserted between each command in a command line.
- Where unit specifiers are omitted, the natural unit (e..g. Volts, Amps) will be assumed.
- Case is significant in unit specifiers, as the SCPI interpreter recognises a wide range of the possible SI prefixes, e.g. m [milli] and M [mega].
- Floating point number should always have a numeral before a decimal point (leading zero).
- Incorrectly formatted commands will be rejected, and an error message returned, eg.
SCPI_proc: unknown cmd [MY_BAD_CMD]
- Only one command may be issued on each command line.
- Floating point values are stored as single-precision. Thus, 7 significant figure accuracy is available, but not required.
Value are generally returned with four decimal places, however accuracy may be limited to less decimal places. See the instrument Specifications table for value limits and accuracy.
In the detailed explanation of commands below
- Square brackets [ ] indicate the type of input required, e.g. [floating point] or [command]
- Angle brackets < > indicate the specific options available, e.g. <ON|OFF> or <CH1|CH2

### SCPI Argument and Return Value Types

Data type | Description
Value | Floating point number. A A leading zero is required for values < 1.0. Actual value set may be constrained by limits embedded in the instrument.
Unit | A one or two character SI value of Amps or Volts (only V, mV, A, mA are recognised).
ON/OFF | String containing the characters {ON | OFF}. Case sensitive.
Group | Integer [1 .. 255]. Group 0 is reserved.
Channel | Integer [0 .. 255]
String | Alpha numeric, plus keyboard symbols, no spaces (ASCII 0x21 .. 0x7E). No quote marks. Case sensitive.

V1.0 – 3 Feb 2021 | Programmable Hybrid Supply Manual | 11

## SCPI Command List

V1.0 – 3 Feb 2021 | Programmable Hybrid Supply Manual | 12

### *IDN?

Command format | *IDN?
Description | Identify the instrument
Return Info | Manufacturer, product type, series No., software version, hardware version
Typical return

### MEASure

Command format | :MEASure:[parameter]?
Description | Query the actual value of a parameter for the current Channel

CURRent?
Command format | :MEASure:CURRent?
Description | Measure output current
Return Info | Floating point
Typical return | 3.00

Voltage?
Command format | :MEASure:VOLTage?
Description | Measure voltage on the output binding posts
Return Info | Floating point Zero if output is OFF
Typical return | 12.00

IVOLtage?
Command format | :MEASure:IVOLtage?
Description | Measure input voltage (from AC-DC converter)
Return Info | Floating point
Typical return | 28.5

### INSTrument

Command format | :INSTrument:[command]
Description | Set or query a setting of the instrument

CHANnel
Command format | :INSTrument:CHANnel CH<1|2>
Description | Set which channel subsequent SOURCE commands will modify This command has no effect in a single channel instrument.
Example | :INST:CHAN CH1

V1.0 – 3 Feb 2021 | Programmable Hybrid Supply Manual | 13

ESTOp
Command format | :INSTrument ESTOp
Description | Turn all outputs OFF for this instrument (and take whatever additional local action has been specified). This is the command executed when the ‘big red button’ on the web monitoring interface is clicked.
Example | :INST:ESTO

### SOURce

Command format | :SOURce:[command]
Description | Set or query operational settings, such as voltage, current, or output status

VOLTage
Command format | :SOURce:VOLTage [float] [unit]
Description | Set the desired output voltage for when the output is ON
Example | Each of these commands will set the target voltage to 2.50V :SOUR:VOLT 2.50V :SOUR:VOLT 2500 mV :SOUR:VOLT 2.50

VOLTage?
Command format | :SOURce:VOLTage?
Description | Query the current target voltage setting
Return Info | Floating point, in Volts.
Typical return | 12.00

CURRent
Command format | :SOURce:CURRent [float] [unit]
Description | Set the current limit target
Example | Each of these commands will set the target limit current to 2.50A :SOUR:CURR 2.50A :SOUR:CURR 2500 mA :SOUR:CURR 2.50

CURRent?
Command format | :SOURce:CURRent?
Description | Measure the target current limit setting
Return Info | Floating point, in Amps
Typical return | 2.00

OUTPut
Command format | :SOURce:OUTPut <ON|OFF>
Description | Turn the output on or off

V1.0 – 3 Feb 2021 | Programmable Hybrid Supply Manual | 14
Example | :SOURce:OUTPut ON :SOURce:OUTPut OFF

OUTPut?
Command format | :SOURce:OUTPut ?
Description | Query the current status of the output
Return Info | Floating point, in Volts.
Typical return | 12.00

PROTection
Command format | :SOURce:PROTection <ON|OFFt>
Description | Enable/disable current limiting.
Example | :SOURce:PROT ON

PROTection?
Command format | :SOURce:PROTection?
Description | Query the current limiting setting
Example | :SOUR:PROT?
Return Info | Integer 0 for OFF, 1 for ON.
Typical return | 1

TEMPerature?
Command format | :SOURce:TEMPerature?
Description | Query the current heatsink temperature
Example | :SOUR:TEMP?
Return Info | Floating point, in degrees C
Typical return | 28.5

### TRACk

A description of tracking modes in is the section Combining Multiple Supplies, above.
Note: When issued via Telnet or Serial USB, tracking commands are only re-broadcast to the entire group only when the appropriate tracking mode is enabled (TRAC:VOLT, TRAC:CURR, :TRAC:REDU).
TRAC:ESTO is always rebroadcast to the group, when tracking is enabled on the connected unit.
Command format | :TRACk:[command]
Description | Set or query values related to tracking between channels or instruments When Tracking is ON, this instrument will transmit and respond to certain commands addressed to the group (depending on the VENAble and CENAble settings).

GROUp
Command format :TRACk:GROUp [integer]

V1.0 – 3 Feb 2021 | Programmable Hybrid Supply Manual | 15
Description | Set the tracking group number. Acceptable numbers are [1 .. 255]. Group 0 is reserved.
Example | :TRACk:GROU 2

GROUp?
Command format | :TRACk:GROUp?
Description | Query the current tracking group number for this instrument
Typical return | 2

ENABle
Command format | :TRACk:ENABle <ON|OFF>
Description | Enable or disable tracking for this instrument.
Example | :TRACK: ENAB ON

ENABle?
Command format | :TRACk:ENABle?
Description | Query the current tracking status number for this instrument.
Typical return | ON

VENAble
Command format | :TRACk:VENAble <ON|OFF>
Description | Enable or disable Voltage tracking. When On, altering the Voltage setting on any of the units will change the setting on any members of the group with this setting enabled (see :TRACk:VOLTage).
Example | :TRACk:VENAble ON

VENAble?
Command format | :TRACk:VENAble?
Description | Query the voltage tracking setting for this instrument.
Typical return | ON

VOLTage
Command format | :TRACk:VOLTage [float]
Description | Set Voltage for this group. When enabled (VENAble = On and TRACk = On), change the Voltage setting on any members of the group with this Voltage tracking enabled. When issued via Telnet or Serial USB. the command is rebroadcast to the wider group when the appropriate tracking mode is enabled, locally.
Example | :TRAC:VOLT 12
The setting is queried with the :SOURce:VOLTage? command.

CENAble
Command format :TRACk:CENAble <ON|OFF>

V1.0 – 3 Feb 2021 | Programmable Hybrid Supply Manual | 16
Description | Enable or disable Current tracking. When On, altering the Current setting on any of the units will change the setting on any members of the group with this setting enabled.
Example | :TRAC: CENA ON

CENAble?
Command format | :TRACk:CENAble?
Description | Query the current tracking for this instrument.
Typical return | ON

CURRent
Command format | :TRACk:CURRent[float]
Description | Set Current limit for this group. When enabled (CENAble = On and TRACk = On), change the Current limit setting on any members of the group with this Voltage tracking enabled. When issued via Telnet or Serial USB. the command is rebroadcast to the wider group when the appropriate tracking mode is enabled, locally.
Example | :TRAC:CURR 3.5
The setting is queried with the :SOURce:CURRent? command

REDUce
Command format | :TRACk:REDUce [float]
Description | When tracking is enabled (TRACk = On), reduce the output voltage of each unit in the group to locally set Voltage value * the argument of this command. When issued via Telnet or Serial USB. the command is rebroadcast to the wider group when the appropriate tracking mode is enabled, locally.
Example | :TRAC:REDU 0.75 Each unit in the current tracking group should reduce its output voltage to 80.0% of its locally set value. If unit XX: has an output voltage setting of 12V, its output voltage will be reduced to 12V * 0.75 = 9V

REDUce?
Command format | :TRACk:REDUce?
Description | Query the current level of group voltage reduction for this unit.
Typical return | 0.80 (Indicating that the output voltage is reduced to 80% of the local setting.)

ESTOp
Command format | :TRACk:ESTOp
Description | Turn output OFF for all members of the group (and take whatever additional local action has been specified). When issued via Telnet or SerialUSB, this message will be rebroadcast to all members of the current tracking group, regardless of Tracking settings.
Example | :TRAC:ESTO

V1.0 – 3 Feb 2021 | Programmable Hybrid Supply Manual | 17

### SYSTem

Command format | :SYSTem:[command]
Description | Set or query system and communications variables, such as hostname and WiFi credentials

SSID
Command format | :SYSTem:SSID [string]
Description | Set the SSID of a preferred WiFi LAN The SSID must be 8 – 32 characters in length to conform with the 802.11 specification.
Example | :SYST:SSID MyHomeWiFi

SSID?
Command format | :SYSTem:SSID?
Description | Returns the SSID of the connected WiFi LAN
Typical return | MyHomeWiFi

PASSphrase
Command format | :SYSTem:PASSphrase [string]
Description | Set the passphrase for the last entered SSID. The argument string is case sensitive. The passphrase must be 8 – 32 characters in length to conform with the 802.11 specification.
Example | :SYST:PASS MYpAssWord23

PASSphrase?
This command is not implemented, as it poses a security vulnerability for the WiFi network.
Command format | :SYSTem:PASSphrase?
Description | Returns a descriptive message.
Typical return | WiFi password is not available remotely

AUTOconnect
Command format | :SYSTem:AUTOconnect <ON|OFF>
Description | Set the instrument to Autoconnect to the WiFi network. Turning this setting OFF effectively disables WiFi
Example | :SYST:AUTO ON

AUTOconnect?
Command format | :SYSTem:AUTOconnect?
Description | Return the autoconnect status
Typical return | 0 (OFF) or 1 (ON)

HOSTname
Command format :SYSTem:HOSTname [string]

V1.0 – 3 Feb 2021 | Programmable Hybrid Supply Manual | 18
Description | This is command will have the same result as setting the instrument using :INSTrument:NAME mDNS will respond to ICMP (ping, DNS) requests to hostname.local allowing the host to be addressed by this name as well as the IP address. The hostname will not change until the WiFi server is re-initialised. Restart, or follow this command with :SYST:AUTO OFF then :SYST:AUTO ON to change the web interface URL.
Example | :SYSTem:HOSTname MYPSU mDNS will respond to ICMP (ping, DNS) requests to MYPSU.local or mypsu.local (case insensitive)

HOSTname?
Command format | :SYSTem:HOSTname?
Description | Return the hostname (same as Instrument name)
Typical return | MYPSU

## SCPI Packet Structure

SCPI commands are sent as ASCII text and the command string is NULL terminated in the packet. Transport (UDP/IP) Headers

Item | Type | Content
IP Header | 20 bytes | Source & Destination Address, Protocol
UDP Header | 8 bytes
Bytes | | Content | Location
2 | | Source Port (optional IPV4, IPV6) | 0-1
2 | | Destination Port | 2-3
2 | | Length | 4-5
2 | | Checksum (optional for IPV4) | 6-7

SCPI packet (follows UDP/IP headers)
Bytes | | Content | Location
4 | char | 'SCPI' | 0-3
4 uint32_t | | Pkt sequence number (0, other than for logging) | 4-7
2 uint16_t | | Message length (max 1024 bytes - to avoid jumbo packets) | 8-9
1 | int8_t | Tracking group (-1 is universal, e.g. all eStop) | 10
16 | char | Sender name or ID? | 11-26
Up to 1024 | char | Content (Always ASCII. SCPI cmds and responses. CSV for logging). | 27-1050
1051 | Total | SCPI packet

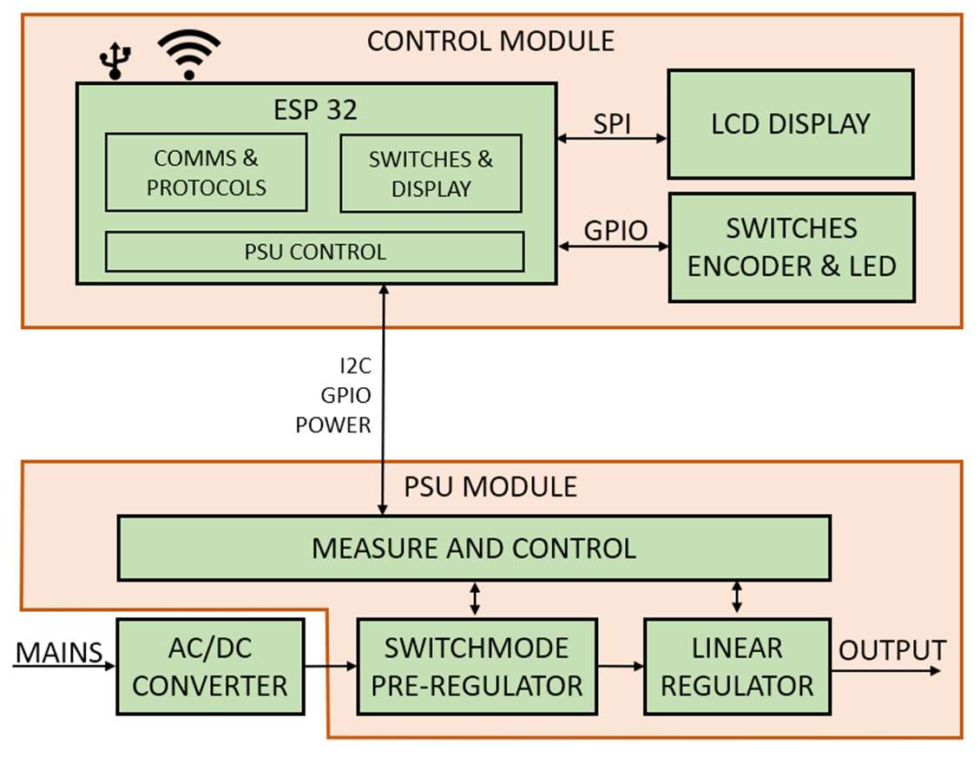
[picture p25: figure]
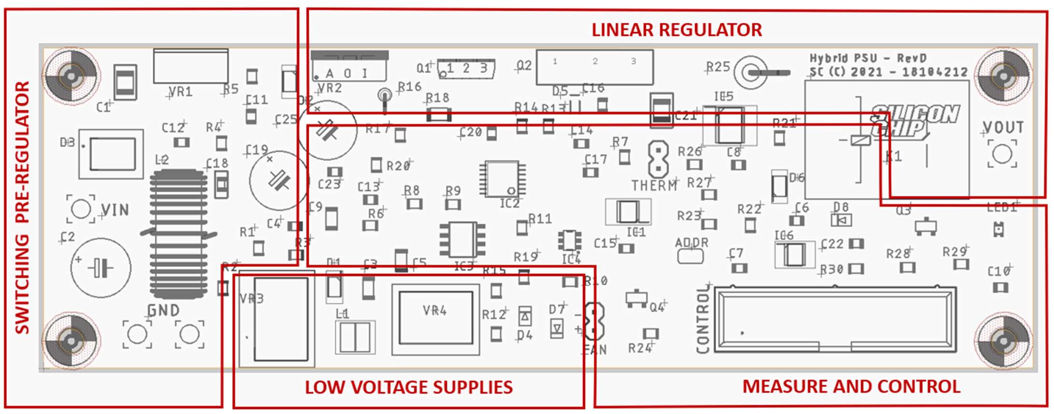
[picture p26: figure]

V1.0 – 3 Feb 2021 | Programmable Hybrid Supply Manual | 19

## Design Overview

The basic design to the power is shown in the block diagram. AC power is converted to 28-30V DC using a commercial 100W switch mode module. This has been chosen, in preference to a traditional transformer design, to reduce size, cost, and weight.

Programmable supply block diagram

Next, a LM2679-based DC-DC buck pre-regulator reduces the DC voltage to 3.6V more than the required output. Finally, a current-boosted linear regulator, based on an LM317, brings the voltage down to the correct output value. Output current is converted to voltage using an INA282 high-side current to voltage converter measuring the voltage drop across an 0.01 ohm shunt resistor. The output voltage and current, along with the input voltage and heatsink temperature, are then measured using a 16-bit ADC. DRDY! signals a complete ADC conversion.
The LM317’s coarse output voltage is controlled by a voltage divider consisting of R20 and the digital pot, IC3, and trimmed using the DAC’s output and opamp IC3A.
All digital control functions use the I2C bus, and the ADDR jumper allows two modules to share a single controller, by altering one bit of each device’s I2C address.

PCB layout (Rev D)

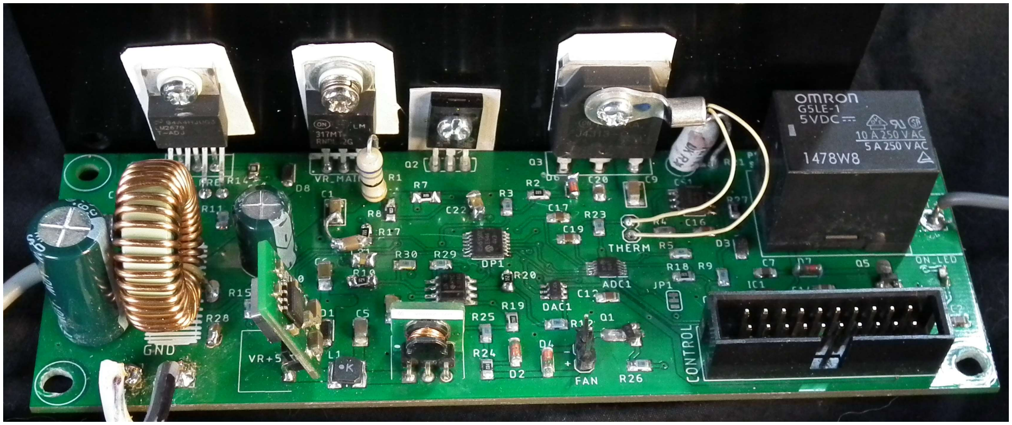
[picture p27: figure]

V1.0 – 3 Feb 2021 | Programmable Hybrid Supply Manual | 20

Prototype (Rev C)

## Schematic

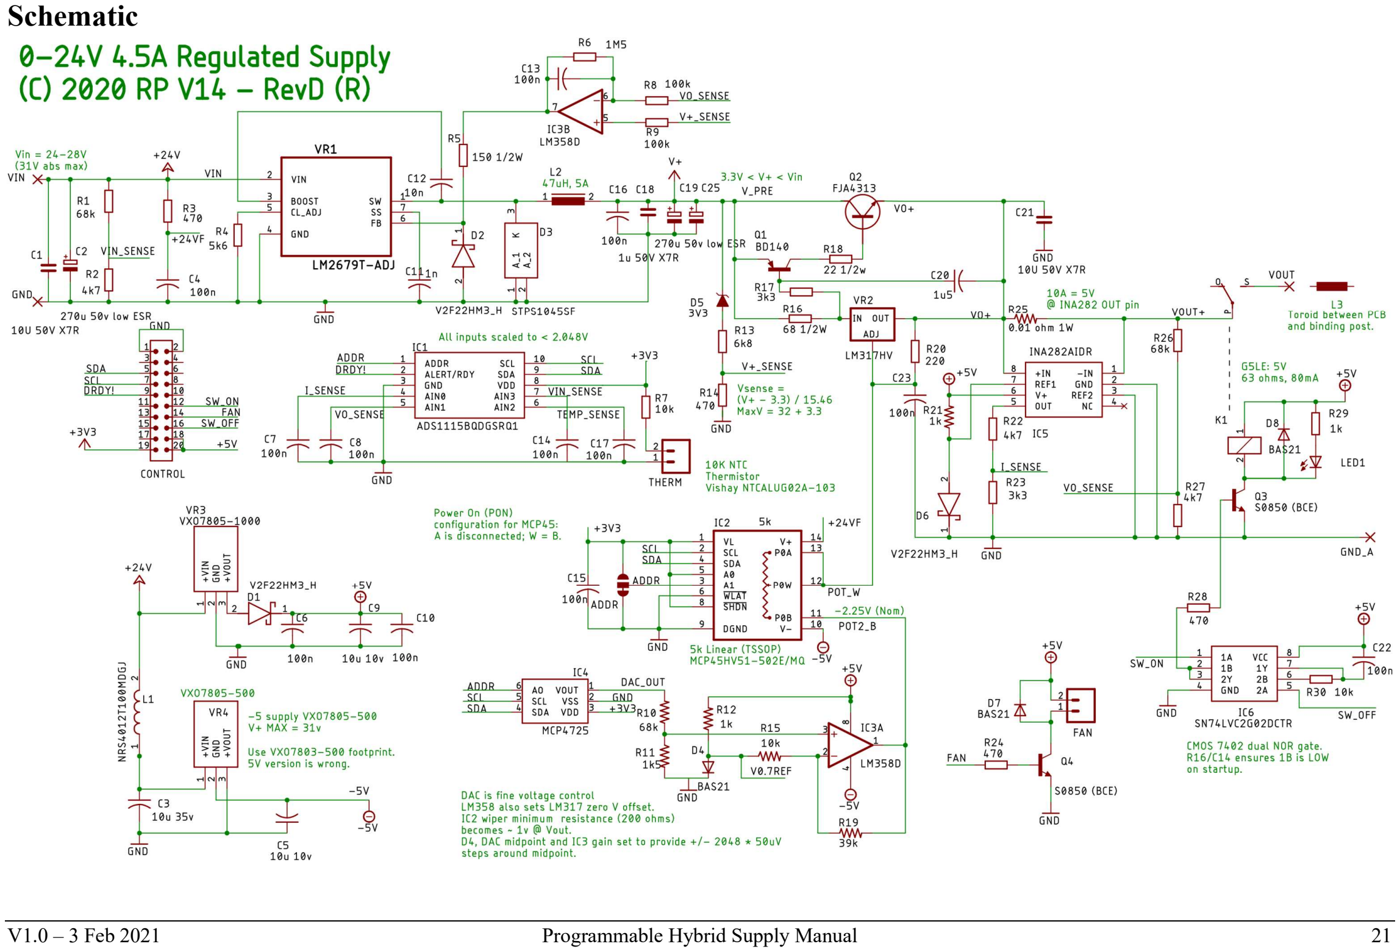
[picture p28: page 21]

V1.0 – 3 Feb 2021 | Programmable Hybrid Supply Manual | 21

V1.0 – 3 Feb 2021 | Programmable Hybrid Supply Manual | 22

## Control header pins

ESP32 IO pins are not 5V tolerant. Only 0 – 3.3V signals should be connected to inputs.

Header Pin | ESP32 Function | GPIO | Header Pin | Function | GPIO
1 | GND | | 2 | GND

3 4

5 | SDA | 21 | 6
7 | SCL | 22 | 8
9 | DRDY! | 2 | 10
11 | 12 | SW_ON | 4
13 | 14 | FAN | 26
15 | 16 | SW_OFF | 12
17 | 18 | +5V (Supply)

19 +3.3V (Return
from ESP32)

20 +5V (Supply)

A Bill of Materials is included in the associated Silicon Chip article (2021).

V1.0 – 3 Feb 2021 | Programmable Hybrid Supply Manual | 23

## Specifications

### Power supply

Output ratings (see also SOA diagram: Fig X)
Low range: 10mV – 16V | 5A
High range: 16V – 26V | 5A @16V tapering to 3.5A @ 24V further reducing to 250mA @26V SOA limiting is always enabled.

Programming accuracy
Voltage | 10mV
Current | 10mV

Control accuracy
Voltage | Better than +/- 5mV when calibrated. No change under load, unless SOA or current limiting is active. On-screen calibration of maximum voltage.
Current | Better than +/- 5mA when calibrated On-screen calibration of maximum current. Zero point is recalibrated when output is OFF for greater than 1 second.

Ripple and noise (no terminal grounded) 20Hz – 20MHz
Voltage | 37mV RMS at full load

Load regulation (change in load current at fixed voltage, measured at front panel binding posts)
Voltage | No measurable change once output has stabilised
Transient response | < 5uS recovery to within 5% of rated voltage (0 – 0.5 A step change with rise time of < 100uS) Full recovery to programmed voltage (within SOA limits) within 5mS. With load rise times of less than 50uS switching transients of up to 3V may occur at load changes greater than 2A. Transients at lower and higher currents are proportional to this value.

Line regulation
(change in voltage under constant resistance load, measured at front panel binding posts)

V1.0 – 3 Feb 2021 | Programmable Hybrid Supply Manual | 24

Settling time after reaching nominal target voltage

< 50mS
Rise time is intentionally limited to 100V/sec.
(0-26V in 260mS)
40V/mS (no load). Shorter fall times under load.
The time constant can be calculated using 10uF and the actual load resistance.
Transient response | Overshoot < 1V Undershoot < 300mV

Readback resolution (SCPI)
Voltage | 1mV
Current | 1 mA

### Communication and remote control

Command processing time
Average time for control change or response after a single command is issued | < 30mS A single waiting command processed every 20mS.

SCPI commands
Units accepted | Volts and millivolts [V | mV]. No unit specified is equivalent to Volts. Amps and milliamps [A | mA]. No unit specified is equivalent to Amps.

Remote control connections
WiFi | 802.11 b/g/n/e/i Auto-connect to the SSID/passphrase combinations provided on the COM menu. WPS is not supported. Where connection to a local WiFi LAN fails, connection is attempted to SSID: ESPINST PW: ESPPW99X If this also fails, a local WiFi network is created with the SSID ESPINST The IP address range provisioned on ESPINST, using DHCP, will be 192.168.50.X DHCP IP address provision in all modes. The current IP address available on the COM menu page DNS name is hostname.local (each instrument implements an mDNS responder) (see SCPI command :INST:NAME and COM menu)

V1.0 – 3 Feb 2021 | Programmable Hybrid Supply Manual | 25
Telnet | Port: 5025 SCPI commands accepted and results returned. Functionality has been tested with the open source software EEZ Studio, and a bare instrument definition for this software is included in the project’s downloads.
Web (HTTP) | A simple web interface is provided which displays the current settings and readings. The page is and not secured or encrypted. The output can be turned off from the web page, but no other settings can be affected. Page refresh rate: 5 seconds Port: 80 http:// hostname.local or http://IPaddress
UDP (packet) | SCPI commands may also be received using UDP packets, although this mechanism is primarily designed for inter-instrument communication when tracking is enabled. Only commands issued by members of the same tracking group are processed. Other messages are discarded. Port: 8888 IP address or hostname as above. Packet specifications are outlined in the SCPI Packet Structure section.
Isolated USB Serial | Damage may occur if a non-isolated USB connection is used. Baud rate: 115,200 SCPI commands accepted and results returned

### Physical and electrical

Electrical
AC input | 100 – 240V 2.1A max < 120W at full load, after start-up.

Physical
Dimensions | 253 x 190 x 82mm
Weight | 1.5kG

V1.0 – 3 Feb 2021 | Programmable Hybrid Supply Manual | 26

## Troubleshooting

Symptom | Likely cause | Remediation
Touch panel not responding. | Touch panel is rotated 180 from LCD. | See the Touch Calibration section.
Touch not centred on buttons. | Touch panel out of register with
LCD.

See the Touch Calibration section.

Voltage or current screen reading
incorrect.
Calibration not completed. | See the Voltage and Current
Calibration sections.

Instruments in a tracking group not tracking.

Voltage &/or Current tracking mode not enabled

See the Tracking Screen section.

Can’t access instrument (Web page or Telnet) remotely.

Wifi not connected.
Instrument has joined the ESPINST WiFi network, rather than the WiFi LAN.
Duplicate hostname.

See Communication Screen and Specifications – WiFi sections.

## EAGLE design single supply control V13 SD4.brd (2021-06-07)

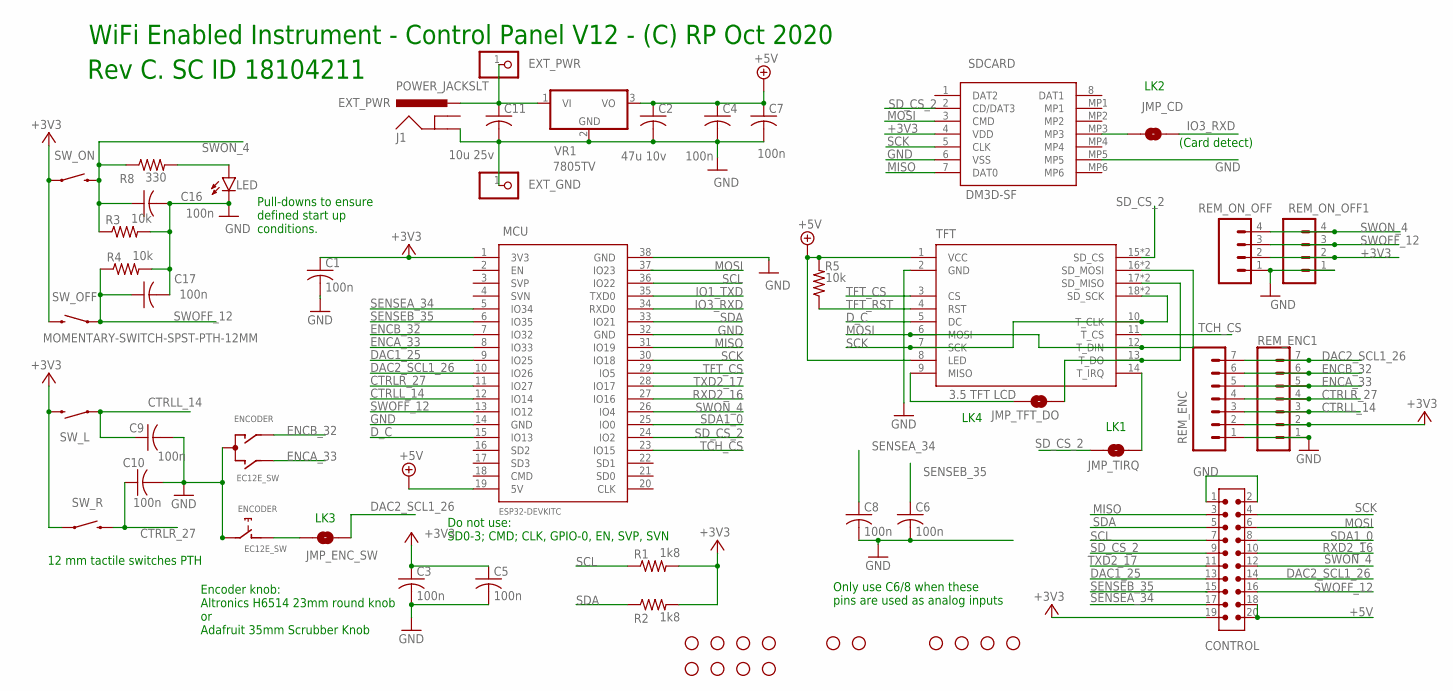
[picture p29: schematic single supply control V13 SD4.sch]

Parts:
C1, C3, C4, C5, C6, C7, C8, C9, C10, C16, C17: 100n; C0805K
C2: 47u 10v; C1210K
C11: 10u 25v; C1210K
CONTROL: 6120XX21621_61202021621; 61202021621
ENCODER: EC12E_SW; ALPS_EC12E_SW
EXT_GND: PINHD-1X1; 1X01
EXT_PWR: PINHD-1X1; 1X01
H1, H2, H3, H4, H5, H6, H7, H8, H9, H10, H11, H12, H13, H14: STAND-OFF
J1: POWER_JACKSLT; POWER_JACK_SLOT
JMP_CD: JUMPER-SMT_2_NO_SILK; SMT-JUMPER_2_NO_SILK
JMP_ENC_SW: JUMPER-SMT_2_NO_SILK; SMT-JUMPER_2_NO_SILK
JMP_TFT_DO: JUMPER-SMT_2_NO_SILK; SMT-JUMPER_2_NO_SILK
JMP_TIRQ: JUMPER-SMT_2_NO_SILK; SMT-JUMPER_2_NO_SILK
LED: LED3MM; LED_3MM
MCU: ESP32DEVKITC; ESP32-DEVKITC
R1, R2: 1k8; R0805W
R3, R4, R5: 10k; R0805W
R8: 330; R0805W
REM_ENC, REM_ENC1: CONN_07; 1X07
REM_ON_OFF, REM_ON_OFF1: CONN_04; 1X04
SDCARD: DM3D-SF; DM3DSF
SW_L: MOMENTARY-SWITCH-SPST-PTH-12MM; TACTILE_SWITCH_PTH_12MM
SW_OFF: MOMENTARY-SWITCH-SPST-PTH-12MM; TACTILE_SWITCH_PTH_12MM
SW_ON: MOMENTARY-SWITCH-SPST-PTH-12MM; TACTILE_SWITCH_PTH_12MM
SW_R: MOMENTARY-SWITCH-SPST-PTH-12MM; TACTILE_SWITCH_PTH_12MM
TFT: 2.8_3.5_TFT_TOUCH; 2.8_3.5_TFT_LCD
VR1: 7805TV; TO220V

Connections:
+3V3: C1.1, C3.1, C5.1, CONTROL.19, MCU.1 (3V3), R1.2, R2.2, REM_ENC.2, REM_ENC1.2, REM_ON_OFF.2, REM_ON_OFF1.2, SDCARD.4 (VDD), SW_L.3 (2), SW_OFF.3 (2), SW_ON.1, SW_R.1
+5V: C2.1, C4.1, C7.1, CONTROL.18, CONTROL.20, MCU.19 (5V), R5.2, TFT.1 (VCC), TFT.8 (LED), VR1.3 (VO)
CTRLL_14: C9.1, MCU.12 (IO14), REM_ENC.3, REM_ENC1.3, SW_L.1
CTRLR_27: C10.1, MCU.11 (IO27), REM_ENC.4, REM_ENC1.4, SW_R.3 (2)
DAC1_25: CONTROL.13, MCU.9 (IO25)
DAC2_SCL1_26: CONTROL.14, JMP_ENC_SW.2, MCU.10 (IO26), REM_ENC.7, REM_ENC1.7
D_C: MCU.15 (IO13), TFT.5 (DC)
ENCA_33: ENCODER.B, MCU.8 (IO33), REM_ENC.5, REM_ENC1.5
ENCB_32: ENCODER.A, MCU.7 (IO32), REM_ENC.6, REM_ENC1.6
ENC_SWX: ENCODER.D (1), JMP_ENC_SW.1
EXT_PWR: C11.1, EXT_PWR.1, J1.PWR, VR1.1 (VI)
GND: C1.2, C2.2, C3.2, C4.2, C5.2, C6.2, C7.2, C8.2, C9.2, C10.2, C11.2, C16.2, C17.2, CONTROL.1, CONTROL.2, ENCODER.C, ENCODER.E (2), EXT_GND.1, J1.GND@2 (GND), LED.K (C), MCU.14 (GND), MCU.32 (GND), MCU.38 (GND), R3.2, R4.2, REM_ENC.1, REM_ENC1.1, REM_ON_OFF.1, REM_ON_OFF1.1, SDCARD.6 (VSS), SDCARD.MP5, TFT.2 (GND), VR1.2 (GND)
IO1_TXD: MCU.35 (TXD0)
IO3_RXD: JMP_CD.2, MCU.34 (RXD0)
MISO: CONTROL.3, JMP_TFT_DO.2, MCU.31 (IO19), SDCARD.7 (DAT0), TFT.13 (T_DO), TFT.17 (SD_MISO), TFT.30 (SD_MISO)
MOSI: CONTROL.6, MCU.37 (IO23), SDCARD.3 (CMD), TFT.6 (MOSI), TFT.12 (T_DIN), TFT.16 (SD_MOSI), TFT.29 (SD_MOSI)
unnamed: JMP_CD.1, SDCARD.MP3
unnamed: JMP_TFT_DO.1, TFT.9 (MISO)
unnamed: JMP_TIRQ.2, TFT.14 (T_IRQ)
unnamed: LED.A, R8.2
RXD2_16: CONTROL.10, MCU.27 (IO16)
SCK: CONTROL.4, MCU.30 (IO18), SDCARD.5 (CLK), TFT.7 (SCK), TFT.10 (T_CLK), TFT.18 (SD_SCK), TFT.31 (SD_SCK)
SCL: CONTROL.7, MCU.36 (IO22), R1.1
SDA: CONTROL.5, MCU.33 (IO21), R2.1
SDA1_0: CONTROL.8, MCU.25 (IO0)
SD_CS_2: CONTROL.9, JMP_TIRQ.1, MCU.24 (IO2), SDCARD.2 (CD/DAT3), TFT.15 (SD_CS), TFT.28 (SD_CS)
SENSEA_34: C8.1, CONTROL.17, MCU.5 (IO34)
SENSEB_35: C6.1, CONTROL.15, MCU.6 (IO35)
SWOFF_12: C17.1, CONTROL.16, MCU.13 (IO12), R4.1, REM_ON_OFF.3, REM_ON_OFF1.3, SW_OFF.1
SWON_4: C16.1, CONTROL.12, MCU.26 (IO4), R3.1, R8.1, REM_ON_OFF.4, REM_ON_OFF1.4, SW_ON.3 (2)
TCH_CS: MCU.23 (IO15), TFT.11 (T_CS)
TFT_CS: MCU.29 (IO5), TFT.3 (CS)
TFT_RST: R5.1, TFT.4 (RST)
TXD2_17: CONTROL.11, MCU.28 (IO17)

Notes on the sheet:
Pull-downs to ensure defined start up conditions.
12 mm tactile switches PTH
Encoder knob: Altronics H6514 23mm round knob or Adafruit 35mm Scrubber Knob
Only use C6/8 when these pins are used as analog inputs
WiFi Enabled Instrument - Control Panel V12 - (C) RP Oct 2020
Do not use: SD0-3; CMD; CLK, GPIO-0, EN, SVP, SVN
Rev C. SC ID 18104211
(Card detect)
LK4
LK1
LK2
LK3

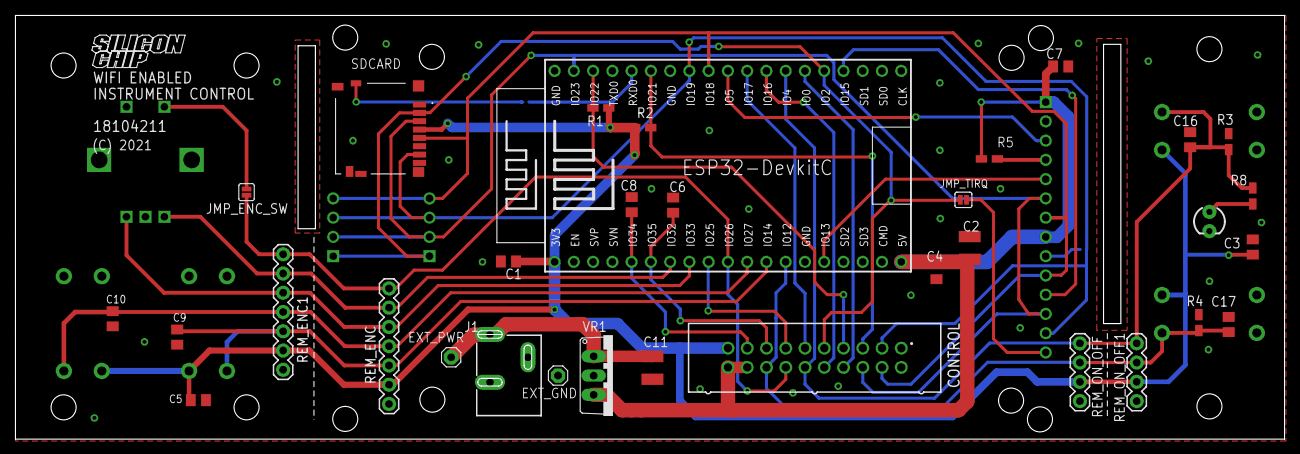
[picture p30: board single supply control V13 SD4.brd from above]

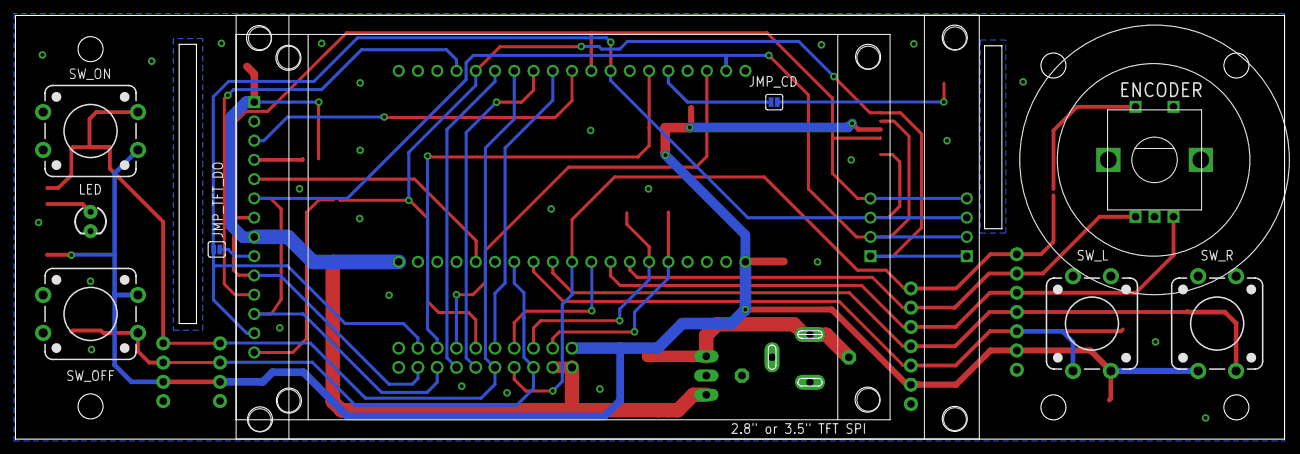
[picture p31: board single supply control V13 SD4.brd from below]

Board: 2 copper layers, 167.4 x 55.9 mm, 55 parts (9 on the bottom side), 33 nets.

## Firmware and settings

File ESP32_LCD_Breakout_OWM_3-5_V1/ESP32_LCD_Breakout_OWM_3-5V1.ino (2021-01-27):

// Demo for SC WiFi Enabled ESP32 LCD Breakout - 3.5" version
// gets time from NTP server; set here below: udp.beginPacket("pool.ntp.org",123);
// gets weather data from https://openweathermap.org/
// this needs a free account and API key, set below at OWM_API_KEY
// you can also change units to F by setting temp_units below (to 'F')

#include "lcd.h"
#include "arial.h"
#include "small_font.h"
#include "gui.h"
#include "graphics.h"
#include "EEPROM.h"
#include "icons.h"
#include <WiFi.h>//#include <ESP8266WiFi.h>
#include <HTTPClient.h>//#include <ESP8266HTTPClient.h>
#include <WiFiUdp.h>
HTTPClient http;        //to keep alive
WiFiUDP udp;            //for NTP
String payload;         //to handle returned payload
#define REFRESH_DELAY (600000UL)
#define OWM_API_KEY "YOUR OWM KEY GOES HERE"
#define NTP_TIMESTAMP_DELTA  2208988800ull

char k[40]="";
char temp_units='C';    //in lieu of anything else, let's save if possible

struct wifinet{
  int ssidLen;
  int bssidLen;
  char ssid[36] = "ABCDEF";  //word align
  char bssid[36]; //word align
};

#define LOCATION_LENGTH 80

struct location{
  int length;
  char name[LOCATION_LENGTH];
};

wifinet currentWifi;
location currentLocation;

unsigned long UTCzero=0;  //corresponds to millis()==0, for RTC, zero=> invalid
long TZoffset=-1;         //in seconds for adjustment of local time, -1 for not set
unsigned long NTPtimeout=0;//don't refresh as often as weather
#define NTP_UPDATE_INTERVAL (360000UL)
boolean NTPstatus=0;      //1 for validly set

void setup() {
  int r;
  unsigned long t0;
  pinMode(17, OUTPUT);
  digitalWrite(17, HIGH);
  Serial.begin(115200);  
  while(!Serial && (millis() < 2000))
    ;
  //load and validate EEPROM, write back if modified    
  EEPROM.begin(512);
  EEPROM.get(0,currentWifi);
  EEPROM.get(80,currentLocation);   //sizeof(wifinet)=80 
  Serial.println("Silicon Chip weather app");
  // Serial.println(currentWifi.ssidLen);
  //Serial.println(currentWifi.bssidLen);
  Serial.println(currentWifi.ssid);
  //Serial.println(strlen(currentWifi.bssid));
  if((currentWifi.ssidLen<0)||(currentWifi.ssidLen>32)){currentWifi.ssidLen=0;}
  if((currentWifi.bssidLen<0)||(currentWifi.bssidLen>32)){currentWifi.bssidLen=0;}
  currentWifi.ssid[currentWifi.ssidLen]=0;      //null term
  currentWifi.bssid[currentWifi.bssidLen]=0;      //null term
  if((currentLocation.length<0)||(currentLocation.length>(LOCATION_LENGTH-2))){currentLocation.length=0;}
  currentLocation.name[currentLocation.length]=0;   //null term
  Serial.print("Location: "); 
  Serial.print(currentLocation.name); Serial.print(" ["); Serial.print(currentLocation.length);Serial.println("]");
  EEPROM.put(0,currentWifi);  
  EEPROM.put(80,currentLocation);   //sizeof(wifinet)=80   
  EEPROM.commit();
  //display
  displaySetup();
  setrotation(3);     //change this and image will adjust
  Serial.println(sizeof(wifinet));
  WiFi.mode(WIFI_STA);
  WiFi.disconnect();
  WiFi.begin(currentWifi.ssid,currentWifi.bssid);
  if(currentLocation.length==0){pickLocation(k,27);}         //on boot, if data empty, prompt
  if(currentWifi.ssidLen==0){pickWifi(k,36);}         //on boot, if data empty, prompt
  udp.begin(2390);
}

void loop() {  
  mainScreen();
}

void getWebData(){
  long n;
  int i;
  char d[32];
  Serial.println("Sending Get Request to Server.......");
  http.begin(String("http://api.openweathermap.org/data/2.5/weather?q=")+String(currentLocation.name)+String("&appid=" OWM_API_KEY));
  http.setReuse(0);
  int httpCode = http.GET();
  //Serial.println(httpCode);
  if(httpCode!=200){
    Serial.println("Error retrieving data.");
    return;
  }
  Serial.print(http.getSize()); Serial.println(" bytes received");
  payload = http.getString();
  http.end();  
  Serial.println(payload);
  //roughly parse JSON result
  float temp, temp_min, temp_max;
  long UTC_time, UTC_TZ,sunrise,sunset;    //Unix time, offset in seconds
  //numeric returns:
  temp=getFloat("\"temp\":",&payload);
  if(temp<10){Serial.println("Parsing error.");return;}
  temp_min=getFloat("\"temp_min\":",&payload);
  if(temp_min<10){Serial.println("Parsing error.");return;}
  temp_max=getFloat("\"temp_max\":",&payload);
  if(temp_max<10){Serial.println("Parsing error.");return;}
  UTC_time=getLong("\"dt\":",&payload);
  if(UTC_time<10){Serial.println("Parsing error.");return;}
  UTC_TZ=getLong("\"timezone\":",&payload);
  sunrise=getLong("\"sunrise\":",&payload);
  if(sunrise<10){Serial.println("Parsing error.");return;}
  sunset=getLong("\"sunset\":",&payload);  
  if(sunset<10){Serial.println("Parsing error.");return;}
  TZoffset=UTC_TZ;          //update
  //string returns
  char icon_id[10]="";    //has surrounding quotes
  const uint8_t* current_icon;
  getChar("\"icon\":",&payload,icon_id,8);
  Serial.println(icon_id);
  current_icon=matchIcon(icon_id);
  if(current_icon != NULL){
   eightBitBitmap(10,50,current_icon);
  }
  //main
  char main_desc[15]="";      //we'll use up to around 12 characters, 1-12
  getChar("\"main\":",&payload,main_desc,14);
  padFix(main_desc+1,12);
  characterarray(120,50,main_desc+1,GUI_FOREGROUND_COLOUR,GUI_BACKGROUND_COLOUR,GUI_FONT);
  //now temp
  characterarray(120,75,"Now ",GUI_FOREGROUND_COLOUR,GUI_BACKGROUND_COLOUR,GUI_FONT);
  drawTemp(184,75,temp);
  //min temp
  characterarray(120,100,"Min ",GUI_FOREGROUND_COLOUR,GUI_BACKGROUND_COLOUR,GUI_FONT);
  drawTemp(184,100,temp_min);
  //max temp
  characterarray(120,125,"Max ",GUI_FOREGROUND_COLOUR,GUI_BACKGROUND_COLOUR,GUI_FONT);
  drawTemp(184,125,temp_max);
  //long

  //full description
  char full_desc[40]="";      //
  getChar("\"description\":",&payload,full_desc,40);
  padFix(full_desc+1,36);
  characterarray(10,150,full_desc+1,GUI_FOREGROUND_COLOUR,GUI_BACKGROUND_COLOUR,myke_font);
  //other
  eightBitBitmap(10,160,icon_sunrise);  
  characterarray(70,172,"Sunrise: ",GUI_FOREGROUND_COLOUR,GUI_BACKGROUND_COLOUR,GUI_FONT);
  eightBitBitmap(10,210,icon_sunset);
  characterarray(70,222,"Sunset:  ",GUI_FOREGROUND_COLOUR,GUI_BACKGROUND_COLOUR,GUI_FONT);
  characterarray(10,263,"Updated at:  ",GUI_FOREGROUND_COLOUR,GUI_BACKGROUND_COLOUR,GUI_FONT);
  drawTime(214,172,sunrise,GUI_FOREGROUND_COLOUR);
  drawTime(214,222,sunset,GUI_FOREGROUND_COLOUR);
  drawTime(214,262,UTC_time,GUI_FOREGROUND_COLOUR);
  Serial.print("Curr temp: "); Serial.println(temp-273.15);
  Serial.print("Min temp:  "); Serial.println(temp_min-273.15);
  Serial.print("Max temp:  "); Serial.println(temp_max-273.15);
  Serial.print("UTC time:  "); Serial.println(UTC_time);
  Serial.print("UTC time:  "); Serial.println(UTC_TZ);
  Serial.print("Sunrise:   "); Serial.println(sunrise);
  Serial.print("Sunset:    "); Serial.println(sunset);
  yield();
}

void drawTemp(int x, int y, float t){   //note t in K, convert to temp_units, 8 characters wide
  long tt;
  boolean flag=0;
  if(temp_units=='C'){
    t=t-273.15;
  }else{
    t=(t*1.8)-459.67;   //assume Fahrenheit
  }
  tt=t*10.0;  //simplify comparisons, now in tenths of  a degree
  if(tt<0){
    tt=-tt;
    x=x+character(x,y,'-',GUI_FOREGROUND_COLOUR,GUI_BACKGROUND_COLOUR,GUI_FONT);
  }else{
    x=x+character(x,y,' ',GUI_FOREGROUND_COLOUR,GUI_BACKGROUND_COLOUR,GUI_FONT);    
  }
  if(tt>9999){tt=9999;}
  if(tt>999){
    flag=1;
    x=x+character(x,y,tt/1000+'0',GUI_FOREGROUND_COLOUR,GUI_BACKGROUND_COLOUR,GUI_FONT);    
  }else{
    x=x+character(x,y,tt/1000+' ',GUI_FOREGROUND_COLOUR,GUI_BACKGROUND_COLOUR,GUI_FONT);        
  }
  tt=tt%1000;
  if((tt>99)||(flag)){
    flag=1;
    x=x+character(x,y,tt/100+'0',GUI_FOREGROUND_COLOUR,GUI_BACKGROUND_COLOUR,GUI_FONT);    
  }else{
    x=x+character(x,y,tt/100+' ',GUI_FOREGROUND_COLOUR,GUI_BACKGROUND_COLOUR,GUI_FONT);        
  }
  tt=tt%100;
  x=x+character(x,y,tt/10+'0',GUI_FOREGROUND_COLOUR,GUI_BACKGROUND_COLOUR,GUI_FONT);    
  x=x+character(x,y,'.',GUI_FOREGROUND_COLOUR,GUI_BACKGROUND_COLOUR,GUI_FONT);    
  x=x+character(x,y,tt%10+'0',GUI_FOREGROUND_COLOUR,GUI_BACKGROUND_COLOUR,GUI_FONT);      
  x=x+character(x,y,0x7F,GUI_FOREGROUND_COLOUR,GUI_BACKGROUND_COLOUR,GUI_FONT);    
  x=x+character(x,y,temp_units,GUI_FOREGROUND_COLOUR,GUI_BACKGROUND_COLOUR,GUI_FONT);    
  
}

void padFix(char* a, int n){  //remove trailing quotes and pad with spaces up til n (to achieve strlen==n)
  int i=0;
  boolean flag=0;   //set on first quote
  while(i<n){
    if(a[i]=='"'){flag=1;}
    if(flag){a[i]=' ';}
    i++;
  }
  a[i]=0;     //null term
}

const uint8_t* matchIcon(char* id){
  const uint8_t* retval = icon_err;    //if no match
  int i;
  for(i=0;i<ICON_LIST_COUNT;i++){
    if((icon_names[i][0]==id[1])&&(icon_names[i][1]==id[2])&&(icon_names[i][2]==id[3])){    //offset by one due to leading quote mark
      retval=icons[i];
    }
  }
  return retval;
}

float getFloat(char* name, String* source){   //find name in source and return corresponding value (as float)
  char d[32];  
  if(getChar(name,source,d,30)){
    return atof(d);
  }
  return 0.0;     //nothing to return    
}

long getLong(char* name, String* source){   //find name in source and return corresponding value (as long)
  char d[32];  
  if(getChar(name,source,d,30)){
    return atol(d);
  }
  return 0;     //nothing to return  
}

int getChar(char* name, String* source, char* dest, int n){   //find name in source and copy value to dest
  int p=0;
  int s=0;
  int f;
  while(p < source->length()){
    if(name[s]==source->charAt(p)){
      s++;
    }else{
      s=0;    //reset on non-match
    }
    p++;
    if(name[s]==0){   //we've hit the trailing null, so it's a match
      f=0;            //reset and use for destination
      while((--n)&&(p < source->length())){
        dest[f]=source->charAt(p);
        p++;
        f++;
      }
      dest[f]=0;      //null term
      return f;
    }
  }
  return 0;
}

boolean doNTPupdate(){
  Serial.println("Updating NTP");
  delay(10);
  byte NTPpacket[48]="";
  unsigned long long ts1,ts2,ts3,ts4,newtime; //UTP uses four timestamps
  int i;
  for(i=0;i<48;i++){NTPpacket[i]=0;}     //clear packet contents 
  NTPpacket[0] = 0xE3;    //set default values for outgoing packet to server
  NTPpacket[2] = 0x06;
  NTPpacket[3] = 0xEC;
  NTPpacket[12]  = 0x31;
  NTPpacket[13]  = 0x4E;
  NTPpacket[14]  = 0x31;
  NTPpacket[15]  = 0x34;
  //dumpNTP(NTPpacket);
  udp.beginPacket("pool.ntp.org",123);    //NTP requests are to port 123
  udp.write(NTPpacket,48);      //buffer 48 bytes
  udp.endPacket();              //send 48 bytes
  ts1=millis64();               //outgoing timestamp
  while((millis64()-ts1<500UL)&(!udp.parsePacket())){yield();}      //wait up to a 0.5s for packet to return
  ts2=millis64();               //return timestamp
  //Serial.println(udp.available());
  udp.read(NTPpacket,48);       //save the returned packet
  //dumpNTP(NTPpacket);
  ts3=(((unsigned long long)NTPpacket[32])<<56)|(((unsigned long long)NTPpacket[33])<<48)|(((unsigned long long)NTPpacket[34])<<40)|(((unsigned long long)NTPpacket[35])<<32)|(((unsigned long long)NTPpacket[36])<<24)|(((unsigned long long)NTPpacket[37])<<16)|(((unsigned long long)NTPpacket[38])<<8)|(((unsigned long long)NTPpacket[39]));
  ts4=(((unsigned long long)NTPpacket[40])<<56)|(((unsigned long long)NTPpacket[41])<<48)|(((unsigned long long)NTPpacket[42])<<40)|(((unsigned long long)NTPpacket[43])<<32)|(((unsigned long long)NTPpacket[44])<<24)|(((unsigned long long)NTPpacket[45])<<16)|(((unsigned long long)NTPpacket[46])<<8)|(((unsigned long long)NTPpacket[47]));
  if((ts3!=0)&&(ts4!=0)){                           //if valid packet returned
    newtime=ts3-NTPfromms(ts1/2+ts2/2);             //time returned by NTP less millis() since boot
    newtime=(newtime>>32)-NTP_TIMESTAMP_DELTA;
    UTCzero=newtime;      //seconds
    Serial.print("Success:");
    Serial.println(UTCzero);
    return 1;
  }
  Serial.println("Fail");
  return 0;    
}

void dumpNTP(byte* p){
  int i;
  char hex[]="0123456789ABCDEF";
  for(i=0;i<48;i++){
    Serial.write(hex[(p[i]>>4)&0xF]);
    Serial.write(hex[(p[i]>>0)&0xF]);
    Serial.write(' ');
    if((i&3)==3){Serial.println();}    
  }
}

void drawTimeSeconds(int x, int y, unsigned long t, unsigned long c){  //convert t to local time and draw
  unsigned long h,m,s;
  char ss[10]="";
  t=t+TZoffset;
  t=t%86400;        //truncate to seconds
  s=t%60;
  t=t/60;
  m=t%60;
  h=t/60;
  ss[0]=(h/10)+'0';
  ss[1]=h%10+'0';
  ss[2]=':';
  ss[3]=(m/10)+'0';
  ss[4]=m%10+'0';
  ss[5]=':';
  ss[6]=(s/10)+'0';
  ss[7]=s%10+'0';
  ss[8]=0;
  characterarray(x,y,ss,c,GUI_BACKGROUND_COLOUR,GUI_FONT);  
}


void drawTime(int x, int y, unsigned long t, unsigned long c){  //convert t to local time and draw
  unsigned long h,m,s;
  char ss[10]="";
  t=t+TZoffset;
  t=t%86400;        //truncate to seconds
  s=t%60;
  t=t/60;
  m=t%60;
  h=t/60;
  ss[0]=(h/10)+'0';
  ss[1]=h%10+'0';
  ss[2]=':';
  ss[3]=(m/10)+'0';
  ss[4]=m%10+'0';
  ss[5]=0;
  characterarray(x,y,ss,c,GUI_BACKGROUND_COLOUR,GUI_FONT);  
}

void mainScreen(){
  unsigned long tmout=0;
  boolean done=0;
  char ipAdd[20]="Test";
  IPAddress ip;
  guiObject setupButton={380,0,100,30,"WiFi",0,0,1,1,BUTTON};  //x,y,w,h,text,value,pressed,visible,enabled,type
  guiObject locButton={0,0,320,40,currentLocation.name,0,0,1,1,BUTTON};
  clear(GUI_BACKGROUND_COLOUR);
  guiDraw(setupButton);
  guiDraw(locButton);
  while(!done){
    delay(10); 
    // Serial.println("MainScreen");
    if(WiFi.status()==WL_CONNECTED){
      if((NTPtimeout==0)||((millis()-NTPtimeout)>NTP_UPDATE_INTERVAL)){
        NTPstatus=doNTPupdate();
        Serial.print("NTP status  = "); Serial.print(NTPstatus ? "Success" : "fail");
        Serial.print(" @ T = ");
        Serial.println((float)millis()/1000);
        if(NTPstatus){
          NTPtimeout=millis();
        }else{
          Serial.println("Retrying NTP in 60 seconds");
          NTPtimeout=millis()+(60000UL)-NTP_UPDATE_INTERVAL;    //retry a minute later if it hasn't worked        
        }
      }
      if((tmout==0)||((millis()-tmout)>REFRESH_DELAY)){
        tmout=millis();
        Serial.print("Periodic refresh at ");   
        Serial.println((float)millis()/1000);         
        getWebData();
      }
      monoBitmap(340,0,GREEN,GUI_BACKGROUND_COLOUR,wifi);
      //Serial.println(WiFi.localIP());
      ip = WiFi.localIP();
      WiFi.localIP().toString().toCharArray(ipAdd,17);    //i know...
      while(strlen(ipAdd)<16){
        ipAdd[strlen(ipAdd)+1]=0;        //ensure next character is nul
        ipAdd[strlen(ipAdd)]=' ';        //pad with spaces
      }
    }else{
      monoBitmap(340,0,RED,GUI_BACKGROUND_COLOUR,wifi);      
      strCopy("---.---.---.--- ",ipAdd,17);
    }
    characterarray(352,32,ipAdd,GUI_FOREGROUND_COLOUR,GUI_BACKGROUND_COLOUR,myke_font);
    if(UTCzero&&(TZoffset!=-1)){      //UTCzero <=> time has been set from NTP at some point, TZ has been set
      drawTimeSeconds(186,293,UTCzero+millis()/1000,(NTPstatus?GUI_FOREGROUND_COLOUR:GUI_DISABLE_COLOUR));      
    }else{
      characterarray(186,293,"--:--:--",GUI_FOREGROUND_COLOUR,GUI_BACKGROUND_COLOUR,arial_font);
    }
    characterarray(10,293,"Local time:",GUI_FOREGROUND_COLOUR,GUI_BACKGROUND_COLOUR,arial_font);
    if(pressWait(&setupButton)){
      pickWifi(k,36);
      clear(GUI_BACKGROUND_COLOUR);
      guiDraw(setupButton);
      guiDraw(locButton);
      tmout=0;      //force refresh
    }
    if(pressWait(&locButton)){
      pickLocation(k,27);
      clear(GUI_BACKGROUND_COLOUR);
      guiDraw(setupButton);
      guiDraw(locButton);
      tmout=0;      //force refresh
    }
  }  
}

int pickLocation(char* a,int n){
  clear(GUI_BACKGROUND_COLOUR);
  if(softKeyboard("Enter location",a,n)){
    String(k).toCharArray(currentLocation.name, 32);
    currentLocation.length=strlen(currentLocation.name);
    Serial.println(currentLocation.length);
    Serial.println(currentLocation.name);
    EEPROM.put(80,currentLocation);   //sizeof(wifinet)=80   
    EEPROM.commit();
  }else{
    Serial.println("CANCELLED");
  }
}

int pickWifi(char* a, int n){ //destination, max length
  boolean done=0;
  guiObject cancelButton={380,0,100,30,"Cancel",0,0,1,1,BUTTON};  //x,y,w,h,text,value,pressed,visible,enabled,type  
  char ssidList[9][36];
  guiObject ssidButton[9]={
    {0,31,320,30,ssidList[0],0,0,1,1,BUTTON},
    {0,63,320,30,ssidList[1],0,0,1,1,BUTTON},
    {0,95,320,30,ssidList[2],0,0,1,1,BUTTON},
    {0,127,320,30,ssidList[3],0,0,1,1,BUTTON},
    {0,159,320,30,ssidList[4],0,0,1,1,BUTTON},
    {0,191,320,30,ssidList[5],0,0,1,1,BUTTON},
    {0,223,320,30,ssidList[6],0,0,1,1,BUTTON},
    {0,255,320,30,ssidList[7],0,0,1,1,BUTTON},
    {0,287,320,30,ssidList[8],0,0,1,1,BUTTON}
  };
  int i,c;      //index, count of ssid's
  clear(GUI_BACKGROUND_COLOUR);
  guiDraw(cancelButton);
  ssidButton[4].text="Scanning...";
  ssidButton[4].pressed=1;
  guiDraw(ssidButton[4]);     //use this cos it's in a good spot
  ssidButton[4].text=ssidList[4];
  ssidButton[4].pressed=0;
  //c=WiFi.scanNetworks();    //async, if problems with sync version below
  WiFi.scanNetworks(true);
  while(WiFi.scanComplete()<0){
    yield();
    if(pressWait(&cancelButton)){
      Serial.println("cancel");
      return 0;
    }    
  }
  c=WiFi.scanComplete();
  Serial.print(c);
  Serial.println(" networks found");
  for(i=0;i<9;i++){
    if(i<c){
      WiFi.SSID(i).toCharArray(ssidList[i], 36);
      ssidButton[i].enabled=1;
      if(strlen(ssidList[i])>18){ssidList[i][14]='.';ssidList[i][15]='.';ssidList[i][16]='.';ssidList[i][17]=0;}   //truncate with ...
      Serial.println(WiFi.SSID(i).c_str());  
    }else{
      ssidList[i][0]=0;  //blank
      ssidButton[i].enabled=0;
    }
    guiDraw(ssidButton[i]);
  }
  while(!done){
    yield();
    if(pressWait(&cancelButton)){
      Serial.println("cancel");
      done=1;
    }
    for(i=0;i<c;i++){
      if(pressWait(&ssidButton[i])){
        Serial.println(i);
        Serial.println(" selected");
        if(getPassword(k,28)){
           WiFi.SSID(i).toCharArray(currentWifi.ssid, 32);
           String(k).toCharArray(currentWifi.bssid, 32);
           currentWifi.ssidLen=strlen(currentWifi.ssid);
           currentWifi.bssidLen=strlen(currentWifi.bssid);
          if((currentWifi.ssidLen<0)||(currentWifi.ssidLen>32)){currentWifi.ssidLen=0;}
          if((currentWifi.bssidLen<0)||(currentWifi.bssidLen>32)){currentWifi.bssidLen=0;}
          currentWifi.ssid[currentWifi.ssidLen]=0;      //null term
          currentWifi.bssid[currentWifi.bssidLen]=0;      //null term
          EEPROM.put(0,currentWifi);  
          EEPROM.commit();
          WiFi.disconnect();
          WiFi.begin(currentWifi.ssid,currentWifi.bssid);
          done=1;                    
        }else{
          done=1;   //bail
        }
      }      
    }
  }
  return 0;
}

int getLocation(char* a, int n){    //thin wrapper
}

int getPassword(char* a, int n){    //thin wrapper
  int r;
  clear(GUI_BACKGROUND_COLOUR);
  r=softKeyboard("Enter password",a,n);
  if(r){
    Serial.println(k);
  }else{
    Serial.println("CANCELLED");
  }
  return r;
}

boolean strCopy(char* src, char* dst, int n){
  int a,i;
  boolean retval=1;
  a=strlen(src)+1;
  if(a>n){a=n;retval=0;}    //copy incomplete
  for(i=0;i<a;i++){
    dst[i]=src[i];
  }
  dst[n-1]=0;               //null term
  return retval;
}

unsigned long long millis64(){      //looks for rollover; as long as it's called every 50 days, it'll be fine
  static unsigned long lo,hi;   //hi and lo 32 bits
  unsigned long newlo=millis(); //check millis()
  if(newlo<lo){hi++;}           //rollover has happened
  lo=newlo;                     //save for next check
  return ((unsigned long long)(hi) << 32) | ((unsigned long long)(lo));  //return 64 bit result
}

unsigned long long NTPfromms(unsigned long long t){      //converts a time in ms to time in 64 bit NTP, max precision, will rollover after 194 years
  return ((t<<22)/1000)<<10;
}

unsigned long msfromNTP(unsigned long long t){      //converts a 64 bit NTP time into ms
  return ((t*1000)>>32);                            //resolution will be lost however we do this
}

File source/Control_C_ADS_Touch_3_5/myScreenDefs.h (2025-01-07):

/* Screen and touch defs 
*/
#ifndef  MYSCREENDEFS_H
#define  MYSCREENDEFS_H

#include "SPI.h"
#include "Adafruit_GFX.h"

#include <XPT2046_Touchscreen.h>

#ifdef ILI9341
#define sx(x)	((short)(x))	// no scaling
#define sy(x)	((short)(x))	// no scaling
#include "Adafruit_ILI9341.h"
Adafruit_ILI9341 tft = Adafruit_ILI9341(TFT_CS, TFT_DC, TFT_RST);
//Adafruit_ILI9341 tft = Adafruit_ILI9341(TFT_CS, TFT_DC, TFT_MOSI, TFT_CLK, TFT_RST, TFT_MISO);
#endif

#ifdef ILI9488
// see also  myInst.h
#define sx(x)	((short)(1.5 * (x)))	  // scale by 480/320 for bigger display
#define sy(x)	((short)(1.333 * (x))) // 320/240
Arduino_DataBus *bus = new Arduino_ESP32SPI(TFT_DC, TFT_CS, TFT_CLK /* SCK */, TFT_MOSI /* MOSI */, -1 /* MISO */, VSPI /* spi_num */);
Arduino_ILI9488_18bit tft =  Arduino_ILI9488_18bit(bus, TFT_RST, 0, false /* IPS */);
#endif

#ifdef ILI9488

	#include "myFonts/DejaVu_Sans_Mono_Bold_18.h"
	#include "myFonts/DejaVu_Sans_Mono_Bold_22.h"
	#include "myFonts/DejaVu_Sans_Mono_Bold_32.h"
	#include "myFonts/DejaVu_Sans_Mono_Bold_42.h"
	
	#define FONT0 DejaVu_Sans_Mono_Bold_18  // smallest
	#define FONT1 DejaVu_Sans_Mono_Bold_22  // small
	#define FONT2 DejaVu_Sans_Mono_Bold_32  // larger
	#define FONT3 DejaVu_Sans_Mono_Bold_42        // biggest
#else
	#include "myFonts/DejaVu_Sans_Mono_Bold_16.h"
	#include "myFonts/DejaVu_Sans_Mono_Bold_18.h"
	#include "myFonts/DejaVu_Sans_Mono_Bold_26.h"
	#include "myFonts/DejaVu_Sans_Mono_Bold_38.h"
	
	#define FONT0 DejaVu_Sans_Mono_Bold_16  // smallest
	#define FONT1 DejaVu_Sans_Mono_Bold_18  // small
	#define FONT2 DejaVu_Sans_Mono_Bold_26  // larger
	#define FONT3 DejaVu_Sans_Mono_Bold_38        // biggest
#endif

#define MY_DARKGREEN 0x03E0
#define MY_RED 0xF800
#define MY_WHITE 0xFFFF
#define MY_YELLOW 0xFFE0
#define MY_GREEN RGB565(0,36,0)
#define RGB565(R, G, B) (((R)<<11)|((G)<<5)|(B))  
#define LIGHTYELLOW RGB565(31,63,0)
#define YELLOW_VL RGB565(31,63,10)
#define CYAN_L RGB565(15,45,31)
#define CYAN_VL RGB565(21,63,31)
#define CYAN_M RGB565(8,32,24)
#define GREEN_L RGB565(5,63,5)
#define CYAN_M RGB565(8,32,24)
#define PINK_M RGB565(31,28,31)
// special colours
#define VOLT_COL LIGHTYELLOW
#define AMP_COL GREEN_L
#define WATT_COL PINK_M
// screen background
#define BGCOL 0 
#define BGHIGH RGB565(5,11,4)  
#define MIDBG RGB565(5,11,4) 
// value text
#define TEXTCOL  MY_YELLOW
#define HIGHLIGHTCOL MY_WHITE
//menu button items
#define BTEXTCOL RGB565(16,32,16) //light grey
#define BHIGHCOL 0xffff  //LIGHTYELLOW // MY_YELLOW // ILI9341_BLACK 
//menu button backgrounds
#define BBORDHIGH BHIGHCOL
#define BBORD BGCOL
#define BBGHIGH RGB565(0,10,22)
#define BBXHIGH RGB565(0,0,9)

// error screen backgrounds
#define ERR_BG_A MY_DARKGREEN
#define ERR_BG_B MY_RED

// indicator BG colours
#define ITRIG MY_RED 			// Action triggered
#define IENABLE	MY_DARKGREEN	// Function enabled
#define IND_ON MY_GREEN
#define IND_OFFC MY_RED
// screen calibration 
struct screenCals {
  int thmin; // tft.pixel (0,0)
  int tvmin;
  int thmax;// tft.pixel (HMAX,VMAX)
  int tvmax;
  int tsRot;	// screen rotation - as some touch screens are rotated 180%
} ;
screenCals sc = {400, 300, 3900, 3700, SCREENROT}; // useful starting values, overwritten by screen cal and EEPROM restore.

// touch units to screen pixel conversions
int16_t pxh (int16_t px){ 
  int x = ((px-sc.thmin)*HMAX)/(sc.thmax-sc.thmin);
  if (x < 0) return 0;
  if (x > HMAX) return HMAX;
  return x;
}
int16_t pxv (int16_t py){ 
    int y = ((py-sc.thmin)*VMAX)/(sc.tvmax-sc.tvmin);
  if (y < 0) return 0;
  if (y > VMAX) return VMAX;
  return y;  
}

XPT2046_Touchscreen ts(TFT_TOUCH_CS);
TS_Point p;
//XPT2046_Touchscreen ts(TFT_TOUCH_CS, TFT_TOUCH_IRQ);
//XPT2046_Touchscreen ts(CS_PIN);  // Param 2 - NULL - No interrupts
//XPT2046_Touchscreen ts(CS_PIN, 255);  // Param 2 - 255 - No interrupts
//XPT2046_Touchscreen ts(CS_PIN, TIRQ_PIN);  // Param 2 - Touch IRQ Pin - interrupt enabled polling

//Adafruit_ILI9341 tft = Adafruit_ILI9341(TFT_CS, TFT_DC, TFT_RST);
//Adafruit_ILI9341 tft = Adafruit_ILI9341(TFT_CS, TFT_DC, TFT_MOSI, TFT_CLK, TFT_RST, TFT_MISO);

#define BVSPACE 50
#define BVSPACE2 30

#define LEGX 22
#define LEG2X 5
#define CIRCX 10
#define VALX 100
#define VAL2X 60
#define CALX 80
#define CAL2X 160
#define CALREADX 240
#define READX 185
#define TOPLINE 50
#define TOPLEG 17 // big enough for a FONT2 character
#define TOPLEGS 15 // big enough for a FONT1 character
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

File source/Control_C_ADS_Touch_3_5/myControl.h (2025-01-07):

#ifndef MYCONTROL_H
#define MYCONTROL_H
/*
Single instrument control for PSU - v2 will allow a control structure to be input, allowing multiple hardware to be controlled via a single controller. (I2C bus extender...)
 *** need to abstract input and outputs for V2 
 Safe start values are written in setup(), prior to control loop firing or previous setpoints being read from EEPROM
 (Enough SMPS to fire up 5V regulator, zero volts main out)
 Uses proportional control, with hysteresis
 iLimit: overrides voltage setpoint. Uses linear V-I approx to estimate correct voltage setpoint to reach current setting
 Remote limiting behaves in the same way, reducing voltage setting proportionately
 Short circuit protection and other errors (overvoltage) turn off output
*/
void onOff(int8_t channel, bool status);
void calSMPS(void);
short SCPIsendGrpMessage(uint8_t tgrp, char *buf);


bool changedLocal = true; // last value changed was local (or remote)

bool fanOn(bool fanSet){
  // turn fan on or off
	pinMode(FANPIN, OUTPUT);
	digitalWrite(FANPIN, fanSet);
	fanIsOn = fanSet;
	return fanIsOn;
}

// update readings from ADC to control values - both actual volts read and real-world values
void getReadings(void){
   // duplicates ADS1115 code, but missing from native ADC handlers
   // convert reading counts to volts
   portENTER_CRITICAL(&mux); // turn off interrupts while getting the ADS converted values
	   myADC[VOUT].curVolts = convertHAL(adsReadings[VOUT], &ADS_HAL); 
	   myADC[VIN].curVolts  = convertHAL(adsReadings[VIN],  &ADS_HAL); 
	   myADC[IOUT].curVolts = convertHAL(adsReadings[IOUT], &ADS_HAL); 
	   myADC[TEMP].curVolts = convertHAL(adsReadings[TEMP], &ADS_HAL); 
   portEXIT_CRITICAL(&mux);
   // convert volts read to real world values
  //convertHAL(adsReadings[adsMux], &ADS_HAL); 
  //Serial.print("*");
   myADC[VOUT].curVal = myADCcalls[VOUT].convert(myADC[VOUT].curVolts, &myADC[VOUT]);
   myADC[VIN].curVal  = myADCcalls[VIN].convert(myADC[VIN].curVolts,   &myADC[VIN]);
   myADC[IOUT].curVal = myADCcalls[IOUT].convert(myADC[IOUT].curVolts, &myADC[IOUT]);
   myADC[TEMP].curVal = myADCcalls[TEMP].convert(myADC[TEMP].curVolts, &myADC[TEMP]);
}
bool shutDown = false;
void errorI(bool shutOff, bool powerDown, float reading, char * errMsg)
{
	char msgBuf[128];
	if (shutOff){		
		onOff(-1, false);    // shut off output		
	}
	if(powerDown){
		shutDown = true;  //change setpoints to safe values		
	}
	// display screen error message, indicator, and store for SCPI 
	sprintf(msgBuf,"*** Error: \n%s \n[%5.2f]\n", errMsg, reading);
	screenError(msgBuf, ERR_BG_B, 10, false);
}

// coarse and fine control for main output with limiting and tracking
// the actual setting (vSetc) may differ from the desired voltage setting (pSetA.voltage)
//   as a result of external tracking and iLimit
// SMPS tracks the actual output voltage + VDROPOUT 
//   but does not go the minimum (start) voltage (VSTART_S)
//  returns the calculated setpoint (after limiting and tracking)

// ******** move myACD to pointer referenced argument for 2CH

/*
int vSetc = WSTART, vSetcS = WSTART_S ,vfSetting = DSTART; // values are settings, not Volts
float vSetpointX, vSetpointR, vSetpointI, vSetpointS, localLimitRatio;
float vLast = 0, vLastSet = 0;
bool iLimit = false;
bool oldTrack = false;
*/
char estop[] = ":TRAC:ESTO";
float control(settings * sp, controls * cp)
{
  float vSetpoint, iSetpoint, iTrack;
  bool limitOn, trackOn;
  float vRead, vReadS, iRead, tRead, vGap;  
  int jump;
  bool rLimit;
  short fjump;
  // vX = myADCcalls[VOUT].readVolts(VPIN);
 
   vSetpoint = sp->voltage; // update settings 
   iSetpoint = sp->current ;
   iTrack = sp->eTrack;
   limitOn = sp->limitOn;
   trackOn = sp->trackOn;
   // sp->voltageS  = vSetpoint + VDROPOUT; // no loger used
   //************ these need to be extracted to a pointer ******************
   vRead  = myADC[VOUT].curVal; // for convenience
   vReadS = myADC[VIN].curVal;
   iRead  = myADC[IOUT].curVal;
   tRead  = myADC[TEMP].curVal; 
   cp->watts = vRead * iRead;
   vGap = vSetpoint - vRead;
 //  Serial.print("CONT");
#ifdef C_DEBUG   
  //  Serial.printf("%i",loopcntr);
	//Serial.printf(" Vin count = %i", adsReadings[VIN]);
	Serial.printf("Lim %s, Trac %s ", (limitOn)? "T" : "F", (trackOn)? "T" : "F");
	if(trackOn) Serial.printf("(%3.1f%)", iTrack*100);
   // Serial.print(": vSet = "); Serial.print(vSetpoint);
  if (limitOn)  Serial.printf(", Iset = %5.3f",  pSetA.current);
    Serial.printf(", Iread = %5.3f", iRead);
	Serial.printf(", IreadV = %5.3f", myADC[IOUT].curVolts);
	//Serial.printf(", Icount = %i", adsReadings[IOUT]);  
   // out of bounds checking: lowError; hiError;
#endif
   if(!startUp) // don't process these immediately after turn on
   {
	   //Serial.printf("\nCE: %5.3f %5.3f\n",iRead , myADC[IOUT].hiError);
	   // serious error conditions - will turn off output and reduce voltage values to safe
	   // will also turn off outputs in the group, if tracking 
	   if (iRead > myADC[IOUT].hiError) // Short circuit protection
	   {
		 //Serial.print("Short circuit\n");
	   	 if(sp->trackOn)
			SCPIsendGrpMessage(sp->trackGrp, estop);
		 errorI(true, false, iRead, "Short circuit \nprotection"); 
	   }
	   
	   if (vRead > myADC[VOUT].hiError) // Output overvoltage
	   {
		 //Serial.printf("Out over error %5.3f [limit  %5.3f]\n",  vRead, myADC[VOUT].hiError);
		 if(sp->trackOn)
			SCPIsendGrpMessage(sp->trackGrp, estop);
		 errorI(true, true, vRead, "Output overvoltage"); 
	   }
	   
	   if (vReadS > myADC[VIN].hiError) // Input overvoltage
	   {
		 if(sp->trackOn)
			SCPIsendGrpMessage(sp->trackGrp, estop);
		 errorI(true, true, vReadS, "Input overvoltage "); 
	   }
		 
	   if (tRead > myADC[TEMP].hiError)
	   {	
	     if(sp->trackOn) // heatsink over temperature
			SCPIsendGrpMessage(sp->trackGrp, estop);
		 errorI(true, true, tRead, "Over temperature");  
	   }	  
   }
   
   if (shutDown || (!sp->outOn)) // set output voltage to zero if E-stop or, output is off (enable SoftStart)
	 vSetpoint = 0.0; 
 
   // fan control
   fanOn(tRead >= pSetA.temperature); // needs hysteresis (fan hunts around)
  
    // control 	
	if (abs(cp->vLastSet - vSetpoint) > 0.05) // reset limiting when setting changes significantly - might not be needed???
	{
		//Serial.print(" R ");
		cp->iLimit = false; // local current limiting needed
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

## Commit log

2021-02-05 Add files via upload
    Improve heat management
2021-06-07 Added 3.5" Power Supply code variant
2021-06-07 Added eagle files
    [single supply control V13 SD4.brd, single supply control V13 SD4.sch]
2022-01-06 Minor changes. Fan pin confirmed as GPIO 26 / Control pin 14
2025-01-06 Rename file to avoid compiler error
    [myScreenDraw.h]
2025-01-06 Use quotes to avoid compiler errors
    [Control_C_ADS_Touch_3_5.ino]

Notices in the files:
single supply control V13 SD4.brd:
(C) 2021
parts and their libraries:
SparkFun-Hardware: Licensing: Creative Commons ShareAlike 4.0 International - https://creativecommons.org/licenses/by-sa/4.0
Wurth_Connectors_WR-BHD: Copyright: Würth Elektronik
